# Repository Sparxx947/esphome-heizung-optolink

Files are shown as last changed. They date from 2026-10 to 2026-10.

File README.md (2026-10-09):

🇬🇧 [English version](README.en.md)

# Heizung · Optolink (Vitotronic 200 KW2 → ESPHome → Home Assistant)

Selbstbau-Lesekopf an der Optolink-Schnittstelle einer Viessmann-Ölheizung. Ein ESP32 mit ESPHome
liest Temperaturen, Brennerzustand, Brennerstunden und **Störmeldungen** aus der Regelung und gibt sie an
Home Assistant weiter. **Bewusst nur lesend** – die Firmware enthält nichts, was in die Regelung schreibt.

> Stand dieser Dokumentation: **08.10.2026**. Gerät geflasht und in HA, **Lesekopf noch nicht gelötet**
> (Fototransistor war für Fr 09.10. angekündigt, ist aber noch nicht da). Alle Optolink-Werte stehen deshalb in HA noch auf `unknown`.

> **Nachbauen:** Eigene Secrets nach der Vorlage [`firmware/secrets.example.yaml`](firmware/secrets.example.yaml)
> anlegen (WLAN, API-Schlüssel, Hotspot-Passwort) und die feste IP an das eigene Netz anpassen. Die Adressen in der
> Firmware gelten für die Vitotronic 200 KW2 – für andere Viessmann-Regelungen stehen sie im
> [openv-Wiki](https://github.com/openv/openv/wiki) (Seite „Adressen“).

---

## 1. Kurzbeschreibung

| | |
|---|---|
| **Anlage** | Ölkessel Viessmann **Vitola 111** (mit integriertem Speicher), Regelung **Vitotronic 200 Typ KW2** (witterungsgeführt, Gerätekennung `0x2098`), Brenner Viessmann VEA I-2 (Bj. 1999, max. 2,0 kg/h ≈ 2,4 l/h) |
| **Einbauort** | Heizungskeller, Lesekopf vorn links am „V“ der Regelung, ESP-Gehäuse magnetisch am Kesselblech |
| **Was gemessen wird** | Brennerstörung (Anzeige **D1**), Sammelstörung, Brenner an/aus, Pumpen, Außen-/Kessel-/Warmwasser-/Vorlauftemperaturen inkl. Sollwerte, Brennerstarts, **Brennerstunden** |
| **Was gesteuert wird** | nichts (absichtlich) |
| **Ziel** | Push bei Brennerstörung (Anlass: Störung D1 am 03./04.10.2026 bei leerem Tank, die niemand bemerkt hat); Ölverbrauch aus Brennerstunden × Düsendurchsatz als Grundlage für eine Tankprognose |

**Prinzip:** Die Vitotronic hat vorn hinter einem „V“-förmigen Ausschnitt zwei Lämpchen – eine IR-Empfangsdiode
(links, rot) und eine IR-Sendediode (rechts, grün). Darüber spricht sie seriell im **KW-Protokoll (VS1), 4800 Baud 8E2**.
Der Lesekopf setzt mit Magneten darauf: eine **IR-LED** (940 nm) sendet in die linke Lampe, ein **Fototransistor**
empfängt von der rechten. Der ESP32 bedient beide über einen UART (RX GPIO16 / TX GPIO17) mit der ESPHome-Komponente
`optolink` aus **ESPHome-PR #4453** (noch nicht in ESPHome gemergt). Schaltung nach VitoWiFi/openv-Wiki.

---

## 2. Status (Stand 08.10.2026)

| Bereich | Status | Datum / Bemerkung |
|---|---|---|
| Konzept, Adressen, Schaltung | ✅ fertig | 04.10. – Adressen aus openv-Tabelle V200KW2, **noch nicht am Display geprüft** |
| Firmware (YAML) | ✅ fertig, kompiliert | 04.10. (RAM 28 %, Flash 50 %), unverändert seither |
| ESP32 geflasht, WLAN, HA | ✅ fertig | 06.10. ~19:40 – `192.168.178.193`, HA-Integration „Heizung“, 24 Entitäten |
| Feste IP im Router | ✅ fertig | 06.10. (DHCP-Reservierung, immer gleiche IP) |
| Im ESPHome Builder | ✅ fertig, online | 06.10. ~20:00 – Builder-Fassung ist ab jetzt **führend** |
| Gehäuse (SCAD/STL) | ✅ fertig | 06.10. Maße eingetragen, 07.10. Boden + Stützen korrigiert („passt jetzt so“, Jens) |
| Gehäuse gedruckt | ✅ gedruckt | 08.10. laut Jens (ob es exakt die Fassung vom 07.10. ist, ist nicht ausdrücklich bestätigt) |
| Lesekopf löten | ⏳ offen | Fototransistor noch nicht geliefert (Stand 09.10. abends), Termin verschoben auf **Sa 10.10.** |
| Inbetriebnahme / Adressen prüfen | ⏳ offen | nach dem Löten, mit `optolink: logger: true` |
| HA-Automationen (Push, Ölverbrauch, Prognose) | ⏳ offen | erst nach erfolgreicher Inbetriebnahme |

---

## 3. Stückliste

Preise und ASINs zum Zeitpunkt der Bestellung (Amazon.de, Oktober 2026).

| Teil | Menge | Bezeichnung / Typ | Bezugsquelle, ASIN, Preis | Status |
|---|---|---|---|---|
| Mikrocontroller | 1 | **ESP32-WROOM-32U DevKitC V4**, USB-C, CP2102, IPEX-Antennenbuchse; Platine 48,24 × 28,15 mm | Amazon **B0F6567LB5**, 13,99 € (2 Stück bestellt, der zweite ist die Tankmessung) | ✅ geliefert 06.10., geflasht |
| Antenne | 1 | 2,4-GHz-Antenne mit IPEX→SMA-Pigtail (SMA-Buchse Ø ~6,4 mm, 1/4″) | im Antennen-Kit des ESP32 enthalten | ✅ vorhanden |
| IR-LED | 1 (+ Reserve) | **Chanzon** IR-LED 940 nm, 3 mm, 100 Stück (Ersatz für SFH487 / SIR 204 aus dem openv-Wiki) | Amazon **B01BVEKXNC**, 7,99 € | ✅ bestellt 04.10., Zustellung 06.10. angekündigt (Eingang nicht ausdrücklich notiert) |
| Fototransistor | 1 (+ Reserve) | **Kingbright L-93DP3C**, 3 mm, 940 nm, 5 Stück (Ersatz für SFH309FA) | Amazon **B01M3PGVRC**, 9,77 € (Marketplace) | ⏳ bestellt, Lieferung war für Fr 09.10. angekündigt – noch nicht da |
| Widerstand | 1 | 220 Ω (Vorwiderstand IR-LED) | AZ-Delivery-Widerstandssortiment | ✅ vorhanden |
| Widerstand | 1 | 10 kΩ (Pull-up Fototransistor) | AZ-Delivery-Widerstandssortiment | ✅ vorhanden |
| Magnete | 4 | Neodym-Scheibenmagnet **10 × 3 mm** (2 im Lesekopf, 2 im Boden des ESP-Gehäuses) | Amazon, Delaga, 50 Stück, 7,99 € | ✅ bestellt 04.10., Zustellung 06.10. angekündigt |
| Verbindungskabel | 4 | Dupont-Jumper **Buchse–Buchse** (F2F), Farbvorschlag rot/schwarz/gelb/grün | ELEGOO-Jumper-Set M2M/F2M/F2F (40 × 20 cm) | ✅ vorhanden |
| Stromversorgung | 1 | USB-C-Kabel + USB-Netzteil 5 V | – | ❓ **nicht in den Notizen** – vermutlich vorhanden, vor Einbau klären |
| Filament | ~20 g (geschätzt) | **PETG** (Wärme am Kessel) | vorhanden | ✅ vorhanden, Gehäuse gedruckt 08.10. |
| Kleber | wenig | Heißkleber (Platine auf Stützen fixieren, optional) bzw. Sekundenkleber für V-Schlüssel (optional) | vorhanden (angenommen) | ✅ |
| Schrauben | 0 | keine – Steckdeckel und Magnete | – | – |
| Werkzeug | – | Lötkolben, Multimeter (Diodentest), Messschieber, 3D-Drucker | vorhanden | ✅ |

Nicht verwendet, aber verwechslungsgefährdet: Das **AZ-Delivery-LED-Sortiment** ist sichtbares Licht und für Optolink
unbrauchbar. Das **ESP32-CAM-Set** (mit MB-Board) bleibt unangetastet – es war ursprünglich vorgesehen, wurde am
04.10. aber zugunsten eines neuen ESP32 verworfen.

Original-Bauteile laut openv/VitoWiFi: IR-LED **SFH487** (bzw. SIR 204 EVL), Fototransistor **SFH309FA** – bei Amazon
nicht erhältlich, bei Problemen als Tausch bei Reichelt möglich.

---

## 4. Pinbelegung und Verdrahtung

Schaltplan zum Ausdrucken: [`plaene/optolink-schaltplan.pdf`](plaene/optolink-schaltplan.pdf)
(SVG: [`plaene/optolink_plan.svg`](plaene/optolink_plan.svg), Erzeuger: [`plaene/optolink_plan.py`](plaene/optolink_plan.py)).

```
3,3 V ── 220 Ω ── IR-LED (Anode) │ Kathode ── GPIO17 (TX)
3,3 V ── 10 kΩ ──┬── GPIO16 (RX)
                 └── Kollektor Fototransistor │ Emitter ── GND
```

**Die Widerstände sitzen im Lesekopf**, zum ESP gehen nur vier Leitungen:

| Leitung | ESP32-Pin (Aufdruck) | Im Lesekopf an | Farbvorschlag |
|---|---|---|---|
| 1 | `3V3` | 220 Ω (zur LED-Anode) **und** 10 kΩ (zum FT-Kollektor) | rot |
| 2 | `GND` | Emitter Fototransistor | schwarz |
| 3 | `GPIO17` / „TX2“ / „17“ | Kathode IR-LED | gelb |
| 4 | `GPIO16` / „RX2“ / „16“ | Kollektor Fototransistor + 10 kΩ | grün |

**Beinchen:**

| Bauteil | Langes Bein | Kurzes Bein | Quelle |
|---|---|---|---|
| IR-LED (Chanzon) | Anode (+) → 220 Ω | Kathode (flache Seite) → GPIO17 | übliche LED-Konvention |
| Fototransistor L-93DP3C | Emitter → GND | **Kollektor** → GPIO16 + 10 kΩ | Kingbright-Datenblatt (DSAC1289), geprüft 06.10. |

Der Ausdruck nennt beim Fototransistor noch „meist kurzes Bein – prüfen!“; das ist inzwischen per Datenblatt bestätigt.
Trotzdem vor dem Löten mit dem Diodentest des Multimeters gegenprüfen. Falsch herum geht nichts kaputt, es kommen
nur keine Daten.

**Lage im Kopf** (Blick **auf** die Regelung = Blick auf die Rückseite des Kopfs beim Löten):

| Position | Lampe der Regelung | Funktion der Regelung | Unser Bauteil |
|---|---|---|---|
| links | rot („Störung“) | IR-Empfänger | **IR-LED** |
| rechts | grün („Betrieb“) | IR-Sender | **Fototransistor** |

Abstand der Lampen Mitte–Mitte: **14,4 mm** (Jens gemessen 06.10.; openv-Wiki nennt 14 mm).
Im Kopf ist innen „LED“, „FT“ und „OBEN“ eingeprägt.

---

## 5. Gehäuse

Quelle: [`gehaeuse/optolink-gehaeuse.scad`](gehaeuse/optolink-gehaeuse.scad) (OpenSCAD, parametrisch; Teil über
`TEIL = "…"` wählen). Geometrie des Kopfs angelehnt an `vito.scad` aus dem openv-Wiki.

| STL | Wofür | Maße (aus SCAD) | Druckausrichtung |
|---|---|---|---|
| [`kopf.stl`](gehaeuse/kopf.stl) | Lesekopf: Frontplatte 4 mm mit zwei Fenstern Ø 3,2 mm (14,4 mm Abstand), Kragenanschlag für die Bauteilfüße, 2 Magnettaschen 10,3 × 3,2 mm (0,6 mm Restwand zur Front), Hohlraum 12 mm für Widerstände, Kabelauslass 7 × 4 mm oben | Ø 34 mm, 16 mm tief | **Front aufs Bett** |
| [`kopf_deckel.stl`](gehaeuse/kopf_deckel.stl) | Rückdeckel mit Steckkragen und Kabelauslass für 4 Litzen | Ø 34 mm | flach |
| [`v_schluessel.stl`](gehaeuse/v_schluessel.stl) | Führungs-„V“, wird mit 2-mm-Zapfen in die Front gesteckt (ggf. geklebt) und greift ins „V“ der Regelung (ragt 6 mm vor, max. 8 zulässig) | Steg 1,6 mm | stehend |
| [`esp.stl`](gehaeuse/esp.stl) | Gehäuse für den ESP32: USB-C an der linken Stirnseite, SMA-Bohrung Ø 6,6 rechts **unter** der Platine, Dupont-Auslass 12 × 6 mm seitlich unten, Lüftungsschlitze, 2 Magnettaschen im Boden, Prägung „HEIZUNG“ | außen ca. 55,5 × 33,8 × 31 mm, innen 51,5 × 29,8 mm | Boden aufs Bett |
| [`esp_deckel.stl`](gehaeuse/esp_deckel.stl) | Steckdeckel | – | flach |

Vorschauen: [`vorschau_alle.png`](gehaeuse/vorschau_alle.png), [`vorschau_esp.png`](gehaeuse/vorschau_esp.png),
[`vorschau_kopf_vorn.png`](gehaeuse/vorschau_kopf_vorn.png), [`vorschau_kopf_hinten.png`](gehaeuse/vorschau_kopf_hinten.png).

**Druckeinstellungen:** PETG (Kesselnähe), 0,2 mm Schicht, 3 Wände, **ohne Stützmaterial**.

**Bestückung ESP-Gehäuse:** Die Platine liegt mit den beiden Stirnseiten auf **vier Stützen** (je Stirnseite zwei,
17 mm hoch, ca. 4,9 mm breit, 4,5 mm tief), die **zwischen den Stiftleisten** stehen: 3,2 mm Abstand zum Längsrand,
12 mm in der Mitte frei (dort sitzen die USB-Lötlaschen bzw. die SMA-Mutter). Bei Bedarf mit Heißkleber fixieren.
Unter der Platine ist Platz für die nach unten zeigenden Stifte und die Dupont-Buchsen. SMA-Buchse von innen durch
die Bohrung stecken, Mutter außen. Je ein Magnet in die beiden Bodentaschen (von unten), zwei in den Kopf (von hinten).

**Lehren aus den Fehldrucken** (Details in [`docs/verlauf.md`](docs/verlauf.md)):

| Fehler | Ursache | Korrektur |
|---|---|---|
| SMA-Bohrung wäre zugewachsen (06.10.) | lag hinter der rechten Platinenauflage | Bohrung unter die Platine (`sma_z = 8`), 12 mm Lücke für die Mutter |
| Magnettaschen gingen durch den Boden (07.10.) | Tasche 3,2 mm tief in 2,0-mm-Boden | `boden = 4.0` → 0,8 mm Restwand |
| Platine lag auf den Stiften (07.10.) | Stiftleisten laufen über die **ganze** Platinenlänge (19 × 2,54 = 48,3 mm); durchgehende Auflagen blockierten die Pins | 4 Einzelstützen zwischen den Pinreihen |

Regel daraus: Vor jedem STL-Export jede Tasche gegen die Wandstärke prüfen und die Platinen-Unterseite
(Stiftleisten, Buchsen, Lötlaschen) gegen jede Auflage; kritische Maße vorher messen lassen.

---

## 6. Firmware

Datei: [`firmware/heizung-optolink.yaml`](firmware/heizung-optolink.yaml) – entspricht dem Stand im ESPHome Builder.

| Einstellung | Wert |
|---|---|
| Gerätename / Hostname | `heizung-optolink` → `heizung-optolink.local` |
| Anzeigename (`friendly_name`) | `Heizung` |
| IP | **192.168.178.193** (feste DHCP-Reservierung in der FRITZ!Box) |
| Board / Framework | `esp32dev`, **Arduino** (Pflicht für die Optolink-Komponente) |
| Externe Komponente | `github://pr#4453`, Komponente `optolink` |
| Optolink | `protocol: KW`, `rx_pin: GPIO16`, `tx_pin: GPIO17`, `logger: false` (für Inbetriebnahme `true`) |
| Logger | `level: INFO`; UART0 bleibt für das USB-Log frei |
| API | verschlüsselt (`heizung_api_key`) |
| OTA | `platform: esphome`, ohne eigenes Passwort (abgesichert über den API-Schlüssel) |
| Fallback-Hotspot | SSID `Heizung-Fallback`, Passwort aus Secret, mit Captive Portal |

### Entitäten in Home Assistant (24)

Gerät „Heizung“ in der ESPHome-Integration. Die Entity-IDs ergeben sich nach ESPHome-Muster aus
`friendly_name` + Name (z. B. vermutlich `sensor.heizung_brennerstunden`) – **in HA nicht nachgesehen**.

| Name | Typ | Adresse | Format | Intervall |
|---|---|---|---|---|
| Brennerstörung (= Anzeige D1) | binär, problem | `0x0883` | 0/1 | 15 s |
| Sammelstörung | binär, problem | `0x0847` | 0/1 | 15 s |
| Brenner (1. Stufe) | binär, running | `0x0842` | 0/1 | 15 s |
| Speicherladepumpe | binär, running | `0x0845` | 0/1 | 60 s |
| Zirkulationspumpe | binär, running | `0x0846` | 0/1 | 60 s |
| Heizkreispumpe | binär, running | `0x2906` | 0/1 | 60 s |
| Außentemperatur | °C | `0x0800` | 2 B ÷ 10, vorzeichenbehaftet | 120 s |
| Außentemperatur gedämpft | °C | `0x5527` | 2 B ÷ 10, vorzeichenbehaftet | 600 s |
| Kesseltemperatur | °C | `0x0802` | 2 B ÷ 10 | 60 s |
| Kesselsolltemperatur | °C | `0x555A` | 2 B ÷ 10 | 120 s |
| Warmwassertemperatur (Speicher) | °C | `0x0804` | 2 B ÷ 10 | 120 s |
| Vorlauftemperatur (Sensor 17B) | °C | `0x080C` | 2 B ÷ 10 | 120 s |
| Vorlaufsolltemperatur (A1M1) | °C | `0x2544` | 2 B ÷ 10 | 300 s |
| Abgastemperatur (nur mit Abgasfühler sinnvoll) | °C, Diagnose | `0x0808` | 2 B ÷ 10 | 300 s |
| Brennerstarts | Zähler | `0x088A` | 4 B | 300 s |
| Brennerstunden (Stufe 1) | h, total_increasing | `0x08A7` | 4 B, Sekunden ÷ 3600 | 300 s |
| Ölverbrauch Regelung | Diagnose | `0x7574` | 4 B ÷ 1000 – **Bedeutung unklar**, erst beobachten | 1800 s |
| Betriebsart (Rohwert) | Diagnose | `0x2301` | 1 B | 600 s |
| Raumtemperatur Soll | °C, Diagnose | `0x2306` | 1 B | 600 s |
| Optolink-Warteschlange | Diagnose | – | `QUEUE_SIZE` | 60 s |
| Gerätekennung | Text, Diagnose | – | `DEVICE_INFO` | 1800 s |
| Optolink-Status | Text, Diagnose | – | `STATE_INFO` | 30 s |
| WLAN-Signal | dBm | – | – | 120 s |
| Laufzeit | s | – | – | 600 s |

Alle Adressen stammen aus der openv-Tabelle „Adressen“, Spalte V200KW2/KW1, und sind **noch nicht** gegen das
Display der Regelung geprüft.

### Secrets

[`firmware/secrets.example.yaml`](firmware/secrets.example.yaml) ist nur eine Vorlage mit den Schlüsselnamen
`wifi_ssid`, `wifi_password`, `heizung_api_key`, `heizung_ap_password`. **Echte Werte stehen nur im ESPHome Builder**
(dessen `secrets.yaml`), nie im Repo – `.gitignore` schließt `secrets.yaml` und `secrets.*.yaml` aus.
API-Schlüssel erzeugen: `openssl rand -base64 32`.

### Flashen

| Weg | Wann | Wie |
|---|---|---|
| **Builder, OTA** (Normalfall) | jede Änderung | YAML im ESPHome Builder bearbeiten → **INSTALL → Wirelessly** |
| **USB** (Erstflash / Notfall) | leeres Board, Gerät nicht mehr im WLAN | `esphome run heizung-optolink.yaml --no-logs --device /dev/ttyUSB0` mit **echten** Secrets (z. B. per podman-Image `ghcr.io/esphome/esphome`) |
| OTA vom PC (Notweg) | Builder nicht verfügbar | `esphome run … --no-logs --device 192.168.178.193` mit echten Secrets in einer temporären `secrets.yaml`, danach löschen |

> **Falle (06.10. passiert):** Nie einen Prüfbuild mit Dummy-Secrets flashen – das Gerät bekommt dann falsches
> Hotspot-Passwort und falschen API-Schlüssel. Und `esphome upload` **kompiliert nicht neu**, sondern spielt den
> letzten Build aus `.esphome/` auf. Für echte Firmware immer `esphome run`, auf „Successfully compiled“ achten und
> danach per API mit dem echten Schlüssel gegenprüfen.

Der Builder ist die führende Fassung. Wird dort etwas geändert, diese Datei hier nachziehen (und umgekehrt).

---

## 7. Anleitungen

Ausführlich in eigenen Dateien:

- [`docs/einbau.md`](docs/einbau.md) – Aufbau des Lesekopfs, Bestückung des Gehäuses, Montage am Kessel
- [`docs/einmessen.md`](docs/einmessen.md) – Inbetriebnahme, Adressen gegen das Display prüfen, Ölverbrauch aus Brennerstunden eichen
- [`docs/fehlersuche.md`](docs/fehlersuche.md) – bekannte Fehlerbilder mit Ursache und Lösung

### Kurzfassung

1. **Löten:** IR-LED links, Fototransistor rechts (Blick auf die Rückseite des Kopfs, „OBEN“ oben), Beinchen vorher
   per Diodentest prüfen, Widerstände im Kopf, 4 Dupont-Litzen durch den Kabelauslass.
2. **Gehäuse:** Magnete einsetzen, V-Schlüssel in die Front stecken, ESP auf die Stützen, Antenne an SMA.
3. **Firmware:** im Builder `optolink:` → `logger: true` setzen, **INSTALL → Wirelessly**.
4. **Aufsetzen:** Kopf mit dem V in den Ausschnitt der Regelung, ESP-Gehäuse magnetisch ans Kesselblech, USB-Strom.
5. **Prüfen:** Log zeigt Antworten, „Optolink-Status“ verlässt `unknown`, Gerätekennung `0x2098`(?);
   Kessel- und Außentemperatur mit dem Display vergleichen.
6. **Abschließen:** `logger: false`, erneut OTA; HA-Automationen anlegen (Abschnitt 8).

---

## 8. Home-Assistant-Anbindung

Im Repo liegen **keine HA-Pakete** (`ha/` gibt es hier nicht) – die Automationen sind noch nicht angelegt.
Geplant (Stand 04.–08.10.):

| Vorhaben | Grundlage | Status |
|---|---|---|
| Push bei **Brennerstörung** und **Sammelstörung** an die Hausbewohner | `binary_sensor` Brennerstörung / Sammelstörung → `on` | ⏳ geplant |
| Ölverbrauch | Brennerstunden × Düsendurchsatz (≤ 2,4 l/h), an Liefermengen eichen → [`docs/einmessen.md`](docs/einmessen.md) | ⏳ geplant |
| Tankprognose / Warnung | Vorwarnung bei **1.500 l**, dringend bei **800 l** | ⏳ geplant |

**Wichtig für die Automationen:** Ohne Kopf bzw. ohne Verbindung melden die Optolink-Binärsensoren `unknown`, nicht
`off`. Eine Automation „Brennerstörung = aus → alles gut“ würde sonst falsch beruhigen. Auch `unknown`/`unavailable`
über längere Zeit sollte gemeldet werden (Vorschlag, nicht umgesetzt).

Die parallele Füllstandsmessung am Erdtank (pneumatisch, ESP32 „Öltank“ `.194`) ist ein **eigenes Projekt** und
nicht Teil dieses Repos.

---

## 9. Offene Punkte, nächste Schritte, Termine

| Wann | Was | Wer |
|---|---|---|
| **Sa 10.10.2026** (verschoben vom 09.10.) | Sobald ein Fototransistor da ist → Lesekopf löten, aufsetzen, Inbetriebnahme mit `logger: true`. Kommen L-93DP3C und SFH 309 FA beide: **SFH 309 FA** nehmen (Tageslichtfilter); dessen Pinbelegung vor dem Löten im Datenblatt prüfen | Jens |
| beim Einbau | Klären, ob „Gehäuse passt“ (07.10.) nach Druck oder nach Vorschau galt – gedruckt wurde laut Jens am 08.10. | Jens |
| nach dem Löten | Adressen gegen das Display prüfen (v. a. Außen-, Kessel-, Warmwassertemperatur, Brennerzustand) | Jens + Claude |
| nach dem Löten | WLAN-Signal im Keller am Einbauort ablesen (am PC −47 dBm; Testling am Kessel 04.10. −41/−42 dBm) | – |
| danach | Bedeutung von „Ölverbrauch Regelung“ (`0x7574`) und „Betriebsart (Rohwert)“ beobachten | – |
| danach | HA: Push bei Störung, Ölverbrauch, Tankprognose | Claude |
| danach | Startwert für den Ölverbrauch erst nach der Peilung am Tank festlegen (Inhalt seit 05.10. vermutlich ~1.900 l, **unbestätigt**) | Jens |
| offen | Stromversorgung (USB-Netzteil, Kabelweg) am Kessel klären | Jens |
| bestellt 09.10. | **SFH 309 FA** (Reichelt) als Vorsorge, falls der L-93DP3C ausbleibt; SFH487 nur bei schlechtem Empfang | Jens |

---

## 10. Dateiübersicht

| Pfad | Inhalt |
|---|---|
| `README.md` | diese Übersicht |
| `docs/einbau.md` | Aufbau und Montage Schritt für Schritt |
| `docs/einmessen.md` | Inbetriebnahme, Adressprüfung, Ölverbrauchs-Abgleich |
| `docs/fehlersuche.md` | Fehlerbilder, Ursachen, Lösungen |
| `docs/verlauf.md` | Projektverlauf mit Datum |
| `firmware/heizung-optolink.yaml` | ESPHome-Konfiguration (Stand Builder) |
| `firmware/secrets.example.yaml` | Vorlage für die Secrets (ohne echte Werte) |
| `gehaeuse/optolink-gehaeuse.scad` | OpenSCAD-Quelltext aller Gehäuseteile |
| `gehaeuse/kopf.stl`, `kopf_deckel.stl`, `v_schluessel.stl` | Lesekopf mit Deckel und Führungs-V |
| `gehaeuse/esp.stl`, `esp_deckel.stl` | ESP32-Gehäuse mit Deckel |
| `gehaeuse/vorschau_*.png` | Renderbilder |
| `plaene/optolink-schaltplan.pdf` | Schaltplan + Anschlusstabelle + Lage im Kopf (A4) |
| `plaene/optolink_plan.svg` | dasselbe als SVG |
| `plaene/optolink_plan.py` | matplotlib-Skript, das den Plan erzeugt (Ausgabepfade darin sind lokal) |
| `.gitignore` | schließt Secrets, Build-Ordner und Sicherungskopien aus |

**Quellen:** openv-Wiki („Die Optolink-Schnittstelle“, „ESPHome-Optolink“, „Adressen“, `vito.scad`), VitoWiFi,
ESPHome-PR #4453.

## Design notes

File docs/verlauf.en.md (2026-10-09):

🇩🇪 [Deutsche Version](verlauf.md)

# Project history

| Date | What |
|---|---|
| 03./04.10.2026 | Fault **D1** (burner fault) on the Vitotronic – tank empty, nobody noticed. Idea: read out the Optolink and report to HA. |
| 04.10. | Type plate: Vitotronic 200 **KW2**. Approach decided: ESPHome PR #4453 (`protocol: KW`), circuit according to openv/VitoWiFi, addresses from the openv table V200KW2. |
| 04.10. | Wi-Fi test at the boiler with a D1 mini: −41/−42 dBm (AP directly in front of the boiler room). |
| 04.10. | Decision: the ESP32-CAM set remains untouched, instead a new **ESP32-WROOM-32U DevKitC** with external antenna. |
| 04.10. | Ordered: 2× ESP32 + IR LEDs (delivery 06.10.), phototransistor L-93DP3C (delivery 09.10.), magnets 10 × 3 mm (06.10.). |
| 04.10. | `heizung-optolink.yaml` written, validated and compiled (RAM 28 %, flash 50 %); enclosure SCAD + STL first version. |
| 05.10. | Oil delivered (1,500 l), burner runs again after bleeding. |
| 06.10. | Dimensions measured (Jens): board 48.24 × 28.15 mm, USB-C protrudes 1.6 mm, lamp distance **14.4 mm** → SCAD adapted. SMA hole moved below the board. |
| 06.10. ~19:40 | ESP32 flashed, `192.168.178.193`, HA integration "Heizung" (heating) with 24 entities. **Trap:** first flashed the test build with dummy secrets, `upload` did not recompile → corrected with `esphome run` and real secrets. |
| 06.10. ~20:00 | Added to the ESPHome Builder, online; Builder version authoritative from now on. Fixed IP in the FRITZ!Box. |
| 06.10. evening | Datasheet L-93DP3C checked: **collector = short leg**. Circuit diagram printed. |
| 07.10. | First print of the ESP enclosure (Jens) shows two faults: magnet pockets through the floor, supports under the pin headers → floor 4 mm, 4 supports between the pin rows. Jens: "fits like this now". |
| 07.10. | USB access on the PC permanently solved via a udev rule. |
| 08.10. | Optolink enclosure printed (according to Jens). |
| 08.10. | Documentation repo created. |
| 09.10. | Phototransistor (L-93DP3C) not delivered; SFH 309 FA ordered from Reichelt as a fallback. Read-head appointment moved to Sat 10.10. |
| **10.10.** | planned: solder the read head, attach, commissioning with `logger: true`, check addresses (as soon as a phototransistor is available). |

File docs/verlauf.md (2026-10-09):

🇬🇧 [English version](verlauf.en.md)

# Projektverlauf

| Datum | Was |
|---|---|
| 03./04.10.2026 | Störung **D1** (Brennerstörung) an der Vitotronic – Tank leer, niemand hat es bemerkt. Idee: Optolink auslesen und in HA melden. |
| 04.10. | Typschild: Vitotronic 200 **KW2**. Weg festgelegt: ESPHome-PR #4453 (`protocol: KW`), Schaltung nach openv/VitoWiFi, Adressen aus der openv-Tabelle V200KW2. |
| 04.10. | WLAN-Test am Kessel mit einem D1 mini: −41/−42 dBm (AP direkt vor dem Heizungskeller). |
| 04.10. | Entscheidung: ESP32-CAM-Set bleibt unangetastet, stattdessen neuer **ESP32-WROOM-32U DevKitC** mit externer Antenne. |
| 04.10. | Bestellt: 2× ESP32 + IR-LEDs (Zustellung 06.10.), Fototransistor L-93DP3C (Zustellung 09.10.), Magnete 10 × 3 mm (06.10.). |
| 04.10. | `heizung-optolink.yaml` geschrieben, validiert und kompiliert (RAM 28 %, Flash 50 %); Gehäuse-SCAD + STL erster Stand. |
| 05.10. | Öl geliefert (1.500 l), Brenner läuft nach Entlüften wieder. |
| 06.10. | Maße gemessen (Jens): Platine 48,24 × 28,15 mm, USB-C ragt 1,6 mm über, Lampenabstand **14,4 mm** → SCAD angepasst. SMA-Bohrung unter die Platine verlegt. |
| 06.10. ~19:40 | ESP32 geflasht, `192.168.178.193`, HA-Integration „Heizung“ mit 24 Entitäten. **Falle:** zuerst Prüfbuild mit Dummy-Secrets geflasht, `upload` kompilierte nicht neu → mit `esphome run` und echten Secrets korrigiert. |
| 06.10. ~20:00 | Im ESPHome Builder eingetragen, online; Builder-Fassung ab jetzt führend. Feste IP in der FRITZ!Box. |
| 06.10. abends | Datenblatt L-93DP3C geprüft: **Kollektor = kurzes Bein**. Schaltplan gedruckt. |
| 07.10. | Erster Druck des ESP-Gehäuses (Jens) zeigt zwei Fehler: Magnettaschen durch den Boden, Auflagen unter den Stiftleisten → Boden 4 mm, 4 Stützen zwischen den Pinreihen. Jens: „passt jetzt so“. |
| 07.10. | USB-Zugriff am PC per udev-Regel dauerhaft gelöst. |
| 08.10. | Optolink-Gehäuse gedruckt (laut Jens). |
| 08.10. | Doku-Repo angelegt. |
| 09.10. | Fototransistor (L-93DP3C) nicht geliefert; als Vorsorge SFH 309 FA bei Reichelt bestellt. Lesekopf-Termin auf Sa 10.10. verschoben. |
| **10.10.** | geplant: Lesekopf löten, aufsetzen, Inbetriebnahme mit `logger: true`, Adressen prüfen (sobald ein Fototransistor da ist). |

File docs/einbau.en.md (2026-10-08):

🇩🇪 [Deutsche Version](einbau.md)

# Assembly and installation

Step by step from the components to the attached read head. Circuit diagram to keep at hand:
[`../plaene/optolink-schaltplan.pdf`](../plaene/optolink-schaltplan.pdf).

## Prepare beforehand

- printed parts: `kopf` (head), `kopf_deckel` (head lid), `v_schluessel` (V key), `esp`, `esp_deckel` (ESP lid) (PETG)
- IR LED Chanzon 940 nm, phototransistor Kingbright L-93DP3C, 220 Ω, 10 kΩ
- 4 neodymium magnets 10 × 3 mm
- 4 Dupont wires female–female (red, black, yellow, green)
- ESP32-WROOM-32U DevKitC (already flashed) with antenna + IPEX→SMA pigtail
- Soldering iron, multimeter, heat-shrink tubing/insulating tape, hot glue if needed

## 1. Check the components

1. **IR LED:** long leg = anode (+), short leg/flat side = cathode.
   Diode test: red on the anode, black on the cathode → the forward voltage is displayed.
2. **Phototransistor L-93DP3C:** according to the datasheet **collector = short leg**, emitter = long leg.
   Double-check with the multimeter (resistance collector→emitter drops significantly with light or remote-control IR).
3. Installing it the wrong way round destroys nothing – you just get no data.

## 2. Solder the read head

1. Hold the head with its back towards you, embossing **"OBEN" (top) facing up**.
   Then the same side applies as when looking at the controller:
   - **left ("LED")** → IR LED (transmits into the controller's red receiving lamp)
   - **right ("FT", phototransistor)** → phototransistor (receives from the green transmitting lamp)
2. Insert both components from behind into the windows until the component base rests against the collar; the lens is
   flush with the front (4 mm). Secure with a drop of glue if needed.
3. Wire up in the cavity (12 mm deep):

   | From | To |
   |---|---|
   | red (3V3) | 220 Ω → LED anode **and** 10 kΩ → PT collector |
   | yellow (GPIO17) | LED cathode |
   | green (GPIO16) | PT collector (together with the 10 kΩ) |
   | black (GND) | PT emitter |

4. Insulate the solder joints, route the four strands out through the cable outlet at the top (7 × 4 mm).
5. **Two magnets** from behind into the pockets above and below the windows (0.6 mm remaining wall to the front – they hold
   through it). Polarity such that the head sticks to the controller.
6. Plug the **V key** with its 2 mm peg into the pocket in the front (tip pointing down), glue if needed.
7. Push on `kopf_deckel` (head lid); the cable outlet in the push-fit collar must be above the one in the head.

## 3. Fit out the ESP enclosure

1. One magnet each from below into the two floor pockets (0.8 mm remaining wall).
2. SMA socket of the pigtail from the inside through the hole at the bottom right (Ø 6.6 mm), tighten the nut on the outside.
   The hole is deliberately **below** the board.
3. Press the pigtail onto the ESP32's IPEX connector.
4. Plug the Dupont wires onto the pins `3V3`, `GND`, `GPIO17`, `GPIO16` (see the table in the README).
5. Place the board with **USB-C towards the left end face** on the four supports. The supports stand between the
   pin rows; below them there is room for pins and Dupont sockets. Fix with hot glue if needed.
6. Route the Dupont wires through the side outlet (12 × 6 mm, near the USB side).
7. Push on the lid.

## 4. Mounting on the boiler

1. Place the read head with the V key into the "V" cut-out of the Vitotronic (front left); the magnets hold it.
   The V web protrudes 6 mm, the controller allows at most 8 mm.
2. Attach the ESP enclosure magnetically to the boiler sheet metal within reach of the strands.
3. Screw the antenna onto the SMA socket.
4. Connect USB-C power (power supply/cable route not yet defined in the notes).
5. Continue with [`einmessen.en.md`](einmessen.en.md).

## Notes

- The "Entsperrung" (unlock) button on the controller is the **STB** (safety temperature limiter), not the burner reset. The burner reset is the red
  reset button on the burner control unit (Landis & Gyr LOA24). For this project neither needs to be pressed.
- Do not touch the AFRISO leak detector on the tank gauge (belongs to the tank, not to this project).

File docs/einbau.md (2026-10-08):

🇬🇧 [English version](einbau.en.md)

# Aufbau und Einbau

Schritt für Schritt vom Bauteil zum aufgesetzten Lesekopf. Schaltplan zum Danebenlegen:
[`../plaene/optolink-schaltplan.pdf`](../plaene/optolink-schaltplan.pdf).

## Vorher bereitlegen

- gedruckte Teile: `kopf`, `kopf_deckel`, `v_schluessel`, `esp`, `esp_deckel` (PETG)
- IR-LED Chanzon 940 nm, Fototransistor Kingbright L-93DP3C, 220 Ω, 10 kΩ
- 4 Neodym-Magnete 10 × 3 mm
- 4 Dupont-Leitungen Buchse–Buchse (rot, schwarz, gelb, grün)
- ESP32-WROOM-32U DevKitC (schon geflasht) mit Antenne + IPEX→SMA-Pigtail
- Lötkolben, Multimeter, Schrumpfschlauch/Isolierband, ggf. Heißkleber

## 1. Bauteile prüfen

1. **IR-LED:** langes Bein = Anode (+), kurzes Bein/flache Seite = Kathode.
   Diodentest: rot an Anode, schwarz an Kathode → Durchlassspannung wird angezeigt.
2. **Fototransistor L-93DP3C:** laut Datenblatt **Kollektor = kurzes Bein**, Emitter = langes Bein.
   Mit dem Multimeter gegenprüfen (Widerstand Kollektor→Emitter fällt bei Licht bzw. Fernbedienungs-IR deutlich).
3. Falsch eingebaut zerstört nichts – es kommen dann nur keine Daten.

## 2. Lesekopf löten

1. Kopf mit der Rückseite zu dir halten, Prägung **„OBEN“ nach oben**.
   Dann gilt dieselbe Seite wie beim Blick auf die Regelung:
   - **links („LED“)** → IR-LED (sendet in die rote Empfangslampe der Regelung)
   - **rechts („FT“)** → Fototransistor (empfängt von der grünen Sendelampe)
2. Beide Bauteile von hinten in die Fenster stecken, bis der Bauteilfuß am Kragen anliegt; die Linse schließt mit der
   Front (4 mm) bündig ab. Ggf. mit einem Tropfen Kleber sichern.
3. Im Hohlraum (12 mm tief) verdrahten:

   | Von | Nach |
   |---|---|
   | rot (3V3) | 220 Ω → LED-Anode **und** 10 kΩ → FT-Kollektor |
   | gelb (GPIO17) | LED-Kathode |
   | grün (GPIO16) | FT-Kollektor (gemeinsam mit dem 10 kΩ) |
   | schwarz (GND) | FT-Emitter |

4. Lötstellen isolieren, die vier Litzen oben durch den Kabelauslass (7 × 4 mm) führen.
5. **Zwei Magnete** von hinten in die Taschen ober- und unterhalb der Fenster (0,6 mm Restwand zur Front – sie halten
   durch). Polung so, dass der Kopf an der Regelung hält.
6. **V-Schlüssel** mit dem 2-mm-Zapfen in die Tasche in der Front stecken (Spitze nach unten), bei Bedarf kleben.
7. `kopf_deckel` aufstecken; der Kabelauslass im Steckkragen muss über dem im Kopf liegen.

## 3. ESP-Gehäuse bestücken

1. Je einen Magneten von unten in die beiden Bodentaschen (0,8 mm Restwand).
2. SMA-Buchse des Pigtails von innen durch die Bohrung rechts unten (Ø 6,6 mm), Mutter außen festziehen.
   Die Bohrung liegt bewusst **unter** der Platine.
3. Pigtail auf die IPEX-Buchse des ESP32 drücken.
4. Dupont-Leitungen auf die Stifte `3V3`, `GND`, `GPIO17`, `GPIO16` stecken (siehe Tabelle im README).
5. Platine mit **USB-C zur linken Stirnseite** auf die vier Stützen legen. Die Stützen stehen zwischen den
   Stiftreihen; darunter haben Stifte und Dupont-Buchsen Platz. Bei Bedarf mit Heißkleber fixieren.
6. Dupont-Leitungen durch den seitlichen Auslass (12 × 6 mm, nahe der USB-Seite) führen.
7. Deckel aufstecken.

## 4. Montage am Kessel

1. Lesekopf mit dem V-Schlüssel in den „V“-Ausschnitt der Vitotronic setzen (vorn links); die Magnete halten ihn.
   Der V-Steg ragt 6 mm vor, die Regelung erlaubt höchstens 8 mm.
2. ESP-Gehäuse in Reichweite der Litzen magnetisch an das Kesselblech setzen.
3. Antenne an die SMA-Buchse schrauben.
4. USB-C-Strom anschließen (Netzteil/Kabelweg ist in den Notizen noch nicht festgelegt).
5. Weiter mit [`einmessen.md`](einmessen.md).

## Hinweise

- Der „Entsperrung“-Knopf an der Regelung ist der **STB**, nicht der Brenner-Reset. Der Brenner-Reset ist der rote
  Entstörknopf am Feuerungsautomaten (Landis & Gyr LOA24). Für dieses Projekt muss keins von beiden betätigt werden.
- Den AFRISO-Leckanzeiger an der Tankanzeige nicht anfassen (gehört zum Tank, nicht hierher).

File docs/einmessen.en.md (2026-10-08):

🇩🇪 [Deutsche Version](einmessen.md)

# Commissioning and calibration

With Optolink there is nothing analogue to calibrate – the controller delivers finished values. "Calibration" here means:

1. proving **communication**,
2. checking the **addresses** against the controller's display (they come unverified from the openv table),
3. calibrating the **oil consumption** from the burner hours against real delivered or dipped quantities.

## 1. Prove communication

1. In the ESPHome Builder in `heizung-optolink.yaml`:
   ```yaml
   optolink:
     logger: true      # war false
   ```
   (`# war false` = "was false".) If necessary, additionally set `logger: level: DEBUG` in case no Optolink lines appear at `INFO`
   (whether this is needed has **not been checked**).
2. **INSTALL → Wirelessly**, then open **LOGS** in the Builder.
3. Expected:
   - Responses to the requests appear in the log.
   - Text sensor **"Optolink-Status"** changes away from `communication state unknown`.
   - **"Gerätekennung"** (device ID) should identify the V200KW2 (device ID according to openv `0x2098` or identifier `0x00F8`
     in the address table; which format exactly the sensor outputs is open).
   - **"Optolink-Warteschlange"** (Optolink queue) stays small and does not grow steadily.
4. If nothing comes: [`fehlersuche.en.md`](fehlersuche.en.md).

## 2. Check addresses against the display

Compare the values in HA (or in the log) with the Vitotronic's display. Deviations ≤ 0.5 K are rounding.

| Check | HA entity | Address | Comparison on the display | Expectation |
|---|---|---|---|---|
| Outdoor temperature | Außentemperatur | `0x0800` | query outdoor temperature | equal; **negative** in frost (min_value −60 forces signed reading) |
| Boiler | Kesseltemperatur | `0x0802` | boiler temperature | equal |
| Hot water | Warmwassertemperatur | `0x0804` | tank temperature | equal |
| Flow | Vorlauftemperatur | `0x080C` | only if sensor 17B is present | otherwise implausible/constant |
| Flue gas | Abgastemperatur | `0x0808` | only if a flue gas sensor is installed | otherwise implausible → disable entity |
| Burner | Brenner | `0x0842` | flame / burner running | `on` while the burner is running |
| Pumps | Speicherlade-, Zirkulations-, Heizkreispumpe (tank charging, circulation, heating circuit pump) | `0x0845`, `0x0846`, `0x2906` | pump audible/palpable | matches operation |
| Burner hours | Brennerstunden | `0x08A7` | operating hours in the controller | equal (seconds ÷ 3600) |
| Burner starts | Brennerstarts | `0x088A` | burner starts | equal |
| Fault | Brennerstörung / Sammelstörung (burner fault / general fault) | `0x0883` / `0x0847` | fault display | `off` in normal operation |
| Operating mode | Betriebsart (Rohwert) | `0x2301` | set operating mode | note the raw value, observe the mapping |
| Oil consumption controller | Ölverbrauch Regelung | `0x7574` | – | **function unclear** – observe only |

Correct addresses that do not match in the YAML or disable the entity; record the result in [`verlauf.en.md`](verlauf.en.md).
Then `optolink: logger: false` and OTA again.

## 3. Calibrate oil consumption from burner hours

### Basic formula

```
Verbrauch [l] = (Brennerstunden_Ende − Brennerstunden_Anfang) [h] × q [l/h]
```

(Consumption [l] = (burner hours at end − burner hours at start) [h] × q [l/h].)

**Starting value for q:** The burner (VEA I-2) is rated at max. **2.0 kg/h**. With heating oil EL ρ ≈ 0.84 kg/l:

```
q_max = 2,0 kg/h ÷ 0,84 kg/l ≈ 2,38 l/h   (≈ 2,4 l/h)
```

That is the **maximum value**; the actual nozzle is not documented, so q is more likely lower.

### Calibrating against delivered and dipped quantities

Between two points in time with known tank content (dipping or full delivery):

```
q = (Inhalt_Anfang + Lieferungen_dazwischen − Inhalt_Ende) [l]
    ÷ (Brennerstunden_Ende − Brennerstunden_Anfang) [h]
```

(q = (content at start + deliveries in between − content at end) [l] ÷ (burner hours at end − burner hours at start) [h].)

Procedure:

1. **Set the starting point:** dip the tank (dipstick in the manhole) and at the same time note the "Brennerstunden" (burner hours) reading.
   Since the delivery on 05.10. (1,500 l) the content according to the gauge is ~1,900 l – this is **not confirmed**
   (the old pneumatic gauge was silted up). Dipping reference values (horizontal cylinder Ø 1.6 m, ends neglected):
   1,500 l ≈ 42.7 cm, 1,700 l ≈ 46.7 cm, 1,900 l ≈ 50.6 cm.
2. **End point:** at the next delivery or after a few weeks, dip again + note the burner hours.
3. Calculate q using the formula and store it in HA as a factor.
4. Plausibility: previous deliveries (3,000 l on 20.09.2024, 3,000 l on 04.08.2025) lasted ~14 months;
   annual consumption ~2,800 l. With q = 2.38 l/h this would be ~1,180 burner hours/year (**derived**, not measured) –
   an annual value of burner hours from the controller immediately shows whether q is in the right order of magnitude.

### Tank forecast (planned)

```
Restinhalt = Inhalt_Anfang + Lieferungen − q × (Brennerstunden_jetzt − Brennerstunden_Anfang)
```

(Remaining content = content at start + deliveries − q × (burner hours now − burner hours at start).)

Warning thresholds according to the plan: **early warning 1,500 l**, **urgent 800 l**. A suggestion for an HA template sensor,
**not yet set up** and with an **unverified** entity ID:

```yaml
template:
  - sensor:
      - name: Heizöl Restinhalt (Brennerstunden)
        unit_of_measurement: l
        state: >
          {% set h = states('sensor.heizung_brennerstunden') | float(none) %}
          {% if h is none %}{{ none }}{% else %}
          {{ (1900 - 2.38 * (h - BRENNERSTUNDEN_BEI_PEILUNG)) | round(0) }}
          {% endif %}
```

(`Heizöl Restinhalt (Brennerstunden)` = heating oil remaining content (burner hours); `BRENNERSTUNDEN_BEI_PEILUNG` = burner hours at the time of dipping.)

`1900`, `2.38` and `BRENNERSTUNDEN_BEI_PEILUNG` are placeholders – better create them as `input_number` helpers so that
dipping and deliveries can be entered without changing the YAML.

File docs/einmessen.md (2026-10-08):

🇬🇧 [English version](einmessen.en.md)

# Inbetriebnahme und Einmessen

Beim Optolink gibt es nichts analog zu kalibrieren – die Regelung liefert fertige Werte. „Einmessen“ heißt hier:

1. **Kommunikation** nachweisen,
2. **Adressen** gegen das Display der Regelung prüfen (sie stammen ungeprüft aus der openv-Tabelle),
3. den **Ölverbrauch** aus den Brennerstunden an echten Liefer- bzw. Peilmengen eichen.

## 1. Kommunikation nachweisen

1. Im ESPHome Builder in `heizung-optolink.yaml`:
   ```yaml
   optolink:
     logger: true      # war false
   ```
   Ggf. zusätzlich `logger: level: DEBUG` setzen, falls bei `INFO` keine Optolink-Zeilen erscheinen
   (ob nötig, ist **nicht geprüft**).
2. **INSTALL → Wirelessly**, danach im Builder **LOGS** öffnen.
3. Erwartung:
   - Im Log erscheinen Antworten auf die Anfragen.
   - Text-Sensor **„Optolink-Status“** wechselt weg von `communication state unknown`.
   - **„Gerätekennung“** sollte die V200KW2 ausweisen (Geräte-ID laut openv `0x2098` bzw. Kennung `0x00F8`
     in der Adressen-Tabelle; welches Format der Sensor genau ausgibt, ist offen).
   - **„Optolink-Warteschlange“** bleibt klein und läuft nicht stetig hoch.
4. Kommt nichts: [`fehlersuche.md`](fehlersuche.md).

## 2. Adressen gegen das Display prüfen

Werte in HA (oder im Log) mit der Anzeige der Vitotronic vergleichen. Abweichungen ≤ 0,5 K sind Rundung.

| Prüfen | HA-Entität | Adresse | Vergleich am Display | Erwartung |
|---|---|---|---|---|
| Außentemperatur | Außentemperatur | `0x0800` | Abfrage Außentemperatur | gleich; bei Frost **negativ** (min_value −60 erzwingt vorzeichenbehaftetes Lesen) |
| Kessel | Kesseltemperatur | `0x0802` | Kesseltemperatur | gleich |
| Warmwasser | Warmwassertemperatur | `0x0804` | Speichertemperatur | gleich |
| Vorlauf | Vorlauftemperatur | `0x080C` | nur falls Fühler 17B vorhanden | sonst unplausibel/konstant |
| Abgas | Abgastemperatur | `0x0808` | nur falls Abgasfühler verbaut | sonst unplausibel → Entität deaktivieren |
| Brenner | Brenner | `0x0842` | Flamme / Brenner läuft | `on` während der Brenner läuft |
| Pumpen | Speicherlade-, Zirkulations-, Heizkreispumpe | `0x0845`, `0x0846`, `0x2906` | Pumpe hörbar/fühlbar | passt zum Betrieb |
| Brennerstunden | Brennerstunden | `0x08A7` | Betriebsstunden in der Regelung | gleich (Sekunden ÷ 3600) |
| Brennerstarts | Brennerstarts | `0x088A` | Brennerstarts | gleich |
| Störung | Brennerstörung / Sammelstörung | `0x0883` / `0x0847` | Störungsanzeige | im Normalbetrieb `off` |
| Betriebsart | Betriebsart (Rohwert) | `0x2301` | eingestellte Betriebsart | Rohwert notieren, Zuordnung beobachten |
| Ölverbrauch Regelung | Ölverbrauch Regelung | `0x7574` | – | **Funktion unklar** – nur beobachten |

Nicht passende Adressen in der YAML korrigieren oder die Entität deaktivieren; das Ergebnis in [`verlauf.md`](verlauf.md)
nachtragen. Danach `optolink: logger: false` und erneut OTA.

## 3. Ölverbrauch aus Brennerstunden eichen

### Grundformel

```
Verbrauch [l] = (Brennerstunden_Ende − Brennerstunden_Anfang) [h] × q [l/h]
```

**Startwert für q:** Der Brenner (VEA I-2) ist mit max. **2,0 kg/h** angegeben. Mit Heizöl EL ρ ≈ 0,84 kg/l:

```
q_max = 2,0 kg/h ÷ 0,84 kg/l ≈ 2,38 l/h   (≈ 2,4 l/h)
```

Das ist der **Höchstwert**; die tatsächliche Düse ist nicht dokumentiert, q liegt also eher darunter.

### Eichen an Liefer- und Peilmengen

Zwischen zwei Zeitpunkten mit bekanntem Tankinhalt (Peilung oder volle Lieferung):

```
q = (Inhalt_Anfang + Lieferungen_dazwischen − Inhalt_Ende) [l]
    ÷ (Brennerstunden_Ende − Brennerstunden_Anfang) [h]
```

Ablauf:

1. **Anfangspunkt setzen:** Tank peilen (Peilstab im Domschacht) und gleichzeitig den Stand „Brennerstunden“ notieren.
   Seit der Lieferung am 05.10. (1.500 l) liegt der Inhalt laut Anzeige bei ~1.900 l – das ist **nicht bestätigt**
   (die alte pneumatische Anzeige war verschlammt). Peil-Richtwerte (liegender Zylinder Ø 1,6 m, Böden vernachlässigt):
   1.500 l ≈ 42,7 cm, 1.700 l ≈ 46,7 cm, 1.900 l ≈ 50,6 cm.
2. **Endpunkt:** bei der nächsten Lieferung bzw. nach einigen Wochen erneut peilen + Brennerstunden notieren.
3. q nach der Formel rechnen und in HA als Faktor hinterlegen.
4. Plausibilität: Bisherige Lieferungen (3.000 l am 20.09.2024, 3.000 l am 04.08.2025) reichten ~14 Monate;
   Jahresverbrauch ~2.800 l. Bei q = 2,38 l/h wären das ~1.180 Brennerstunden/Jahr (**abgeleitet**, nicht gemessen) –
   ein Jahreswert der Brennerstunden aus der Regelung zeigt sofort, ob q in der richtigen Größenordnung liegt.

### Tankprognose (geplant)

```
Restinhalt = Inhalt_Anfang + Lieferungen − q × (Brennerstunden_jetzt − Brennerstunden_Anfang)
```

Warnschwellen laut Plan: **Vorwarnung 1.500 l**, **dringend 800 l**. Ein Vorschlag für einen HA-Template-Sensor,
noch **nicht eingerichtet** und mit **ungeprüfter** Entity-ID:

```yaml
template:
  - sensor:
      - name: Heizöl Restinhalt (Brennerstunden)
        unit_of_measurement: l
        state: >
          {% set h = states('sensor.heizung_brennerstunden') | float(none) %}
          {% if h is none %}{{ none }}{% else %}
          {{ (1900 - 2.38 * (h - BRENNERSTUNDEN_BEI_PEILUNG)) | round(0) }}
          {% endif %}
```

`1900`, `2.38` und `BRENNERSTUNDEN_BEI_PEILUNG` sind Platzhalter – besser als `input_number`-Helfer anlegen, damit
Peilung und Lieferungen ohne YAML-Änderung nachgetragen werden können.

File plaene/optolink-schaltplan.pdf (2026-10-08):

# Optolink-Lesekopf Schaltplan

Vitotronic 200 KW2 · ESP32-WROOM-32U DevKitC · ESPHome heizung-optolink (192.168.178.193) · Stand 06.10.2026

3V3

## GND

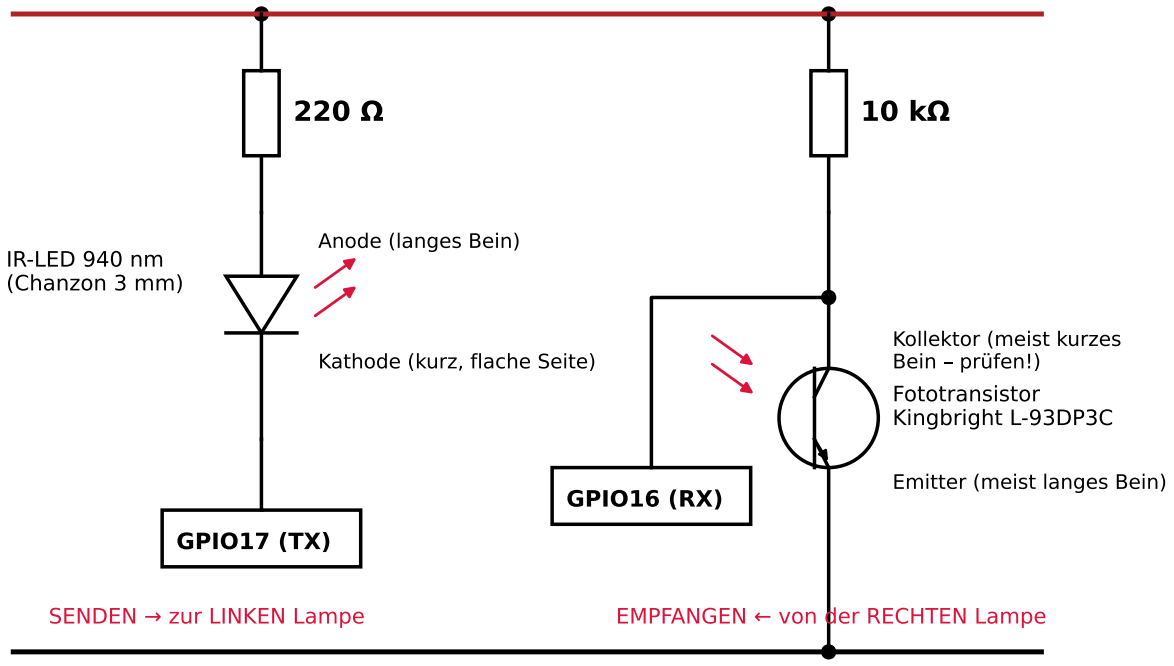
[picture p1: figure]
IR-LED 940 nm (Chanzon 3 mm); Anode (langes Bein); Kathode (kurz, flache Seite); GPIO17 (TX); SENDEN; zur LINKEN Lampe; GPIO16 (RX); Kollektor (meist kurzes; Bein; prüfen!); Emitter (meist langes Bein); Fototransistor Kingbright L-93DP3C; EMPFANGEN; von der RECHTEN Lampe

Achtung Beinchen: Bei der LED ist das LANGE Bein die Anode (+). Beim Fototransistor ist meist das LANGE Bein der Emitter ( ) vor dem Löten am Datenblatt bzw. mit dem Multimeter (Diodentest) prüfen. Falsch herum: nichts kaputt, aber keine Daten.

Verbindung Lesekopf | ESP32 (4 Dupont-Leitungen, Buchse Buchse)
Leitung | ESP32-Pin | Im Lesekopf an | Farbvorschlag
1 | 3V3 | 220 | (LED) + 10 k (FT) | rot
2 | GND | Emitter Fototransistor | schwarz
3 | GPIO17 / TX2 / 17 | Kathode IR-LED | gelb
4 | GPIO16 / RX2 / 16 | Kollektor FT + 10 k | grün

## Lage im Lesekopf (Blick AUF die Regelung = Blick auf die Rückseite des Kopfs)

LED | FT

OBEN

14,4 mm

LINKE Lampe (rot, Störung) = Empfänger der Regelung dort unsere IR-LED

RECHTE Lampe (grün, Betrieb) = Sender der Regelung
dort unser Fototransistor

Abstand Mitte Mitte 14,4 mm (gemessen 06.10.), Kopf-STL ist angepasst

Widerstände sitzen im Kopf, nur 4 Leitungen zum ESP-Gehäuse

Quelle: Schaltung nach VitoWiFi/openv-Wiki ( Die Optolink-Schnittstelle , ESPHome-Optolink ), festgelegt 04.10. in ~/esphome/heizung-optolink.yaml. UART 4800 8E2, Protokoll KW. Inbetriebnahme: optolink logger: true, Werte mit der Anzeige der Regelung vergleichen.

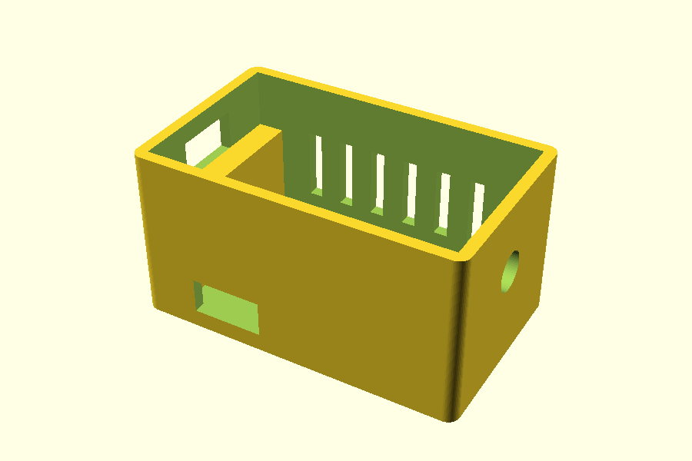
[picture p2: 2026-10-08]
gehaeuse/vorschau_esp.png

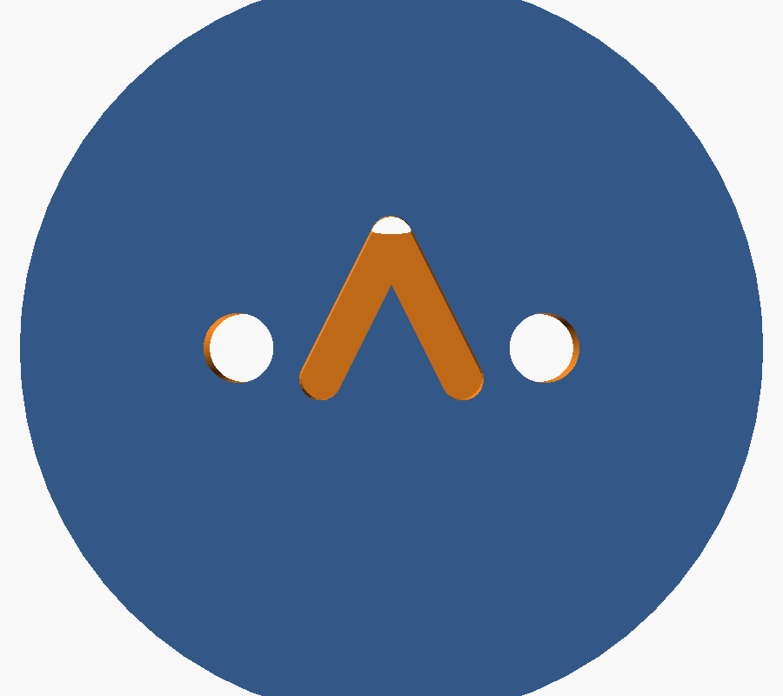
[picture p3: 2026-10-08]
gehaeuse/vorschau_kopf_vorn.png

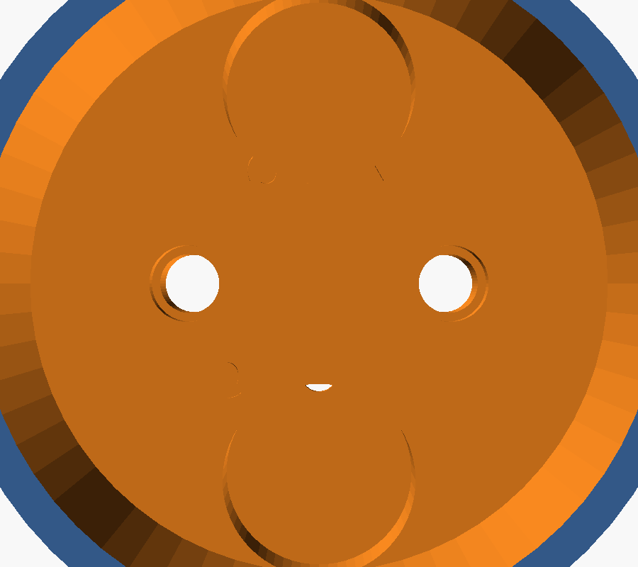
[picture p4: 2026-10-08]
gehaeuse/vorschau_kopf_hinten.png

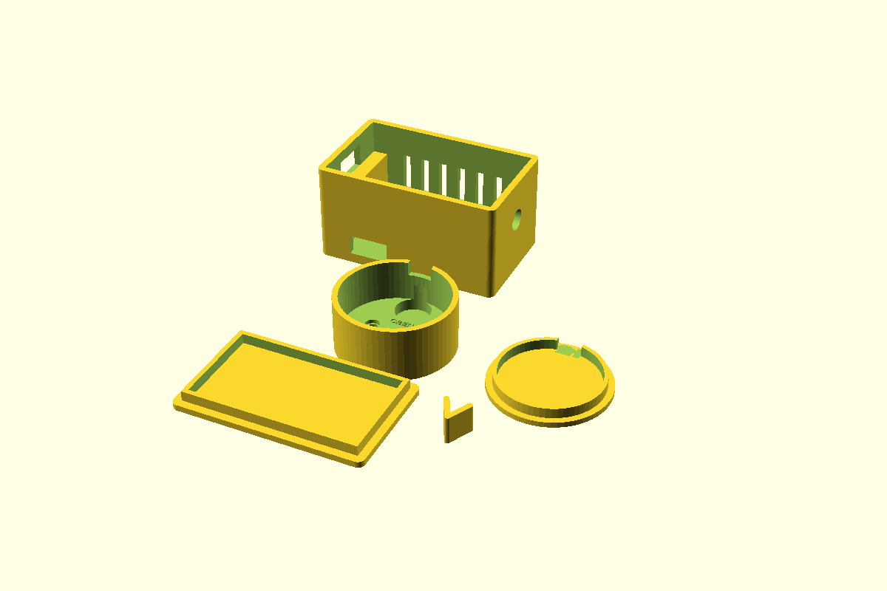
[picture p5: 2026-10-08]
gehaeuse/vorschau_alle.png

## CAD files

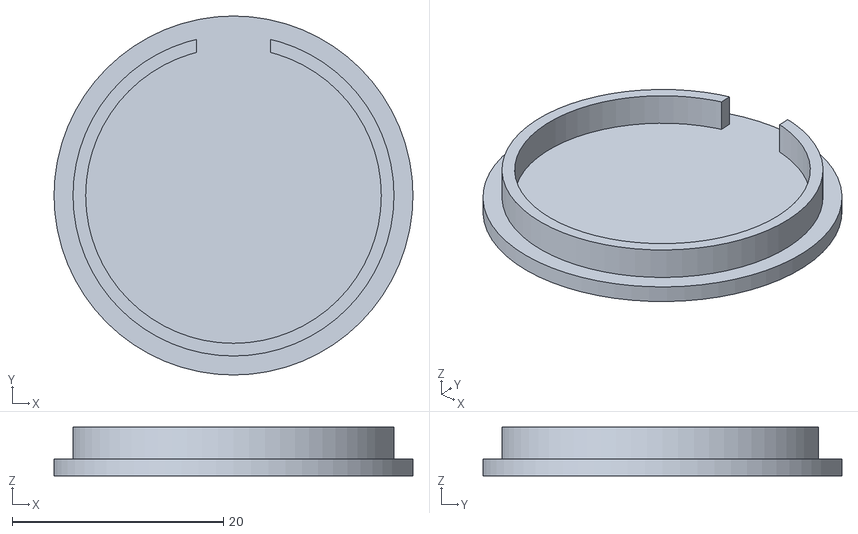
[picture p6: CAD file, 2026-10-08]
gehaeuse/kopf_deckel.stl
34.0 x 34.0 x 4.60

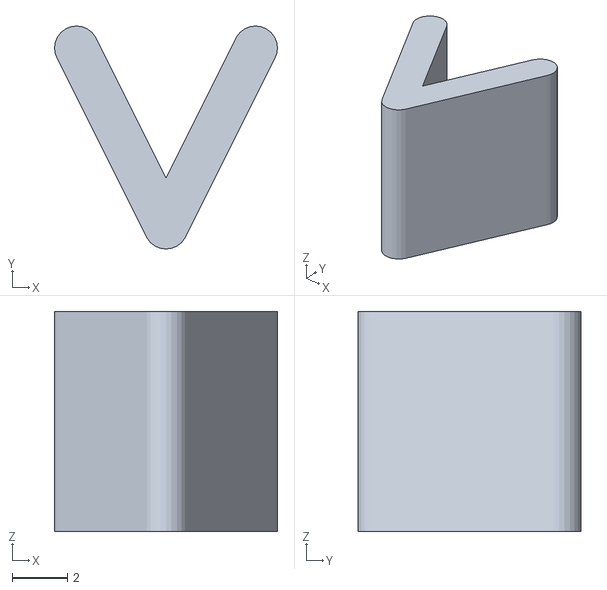
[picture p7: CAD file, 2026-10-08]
gehaeuse/v_schluessel.stl
8.10 x 8.10 x 8.00

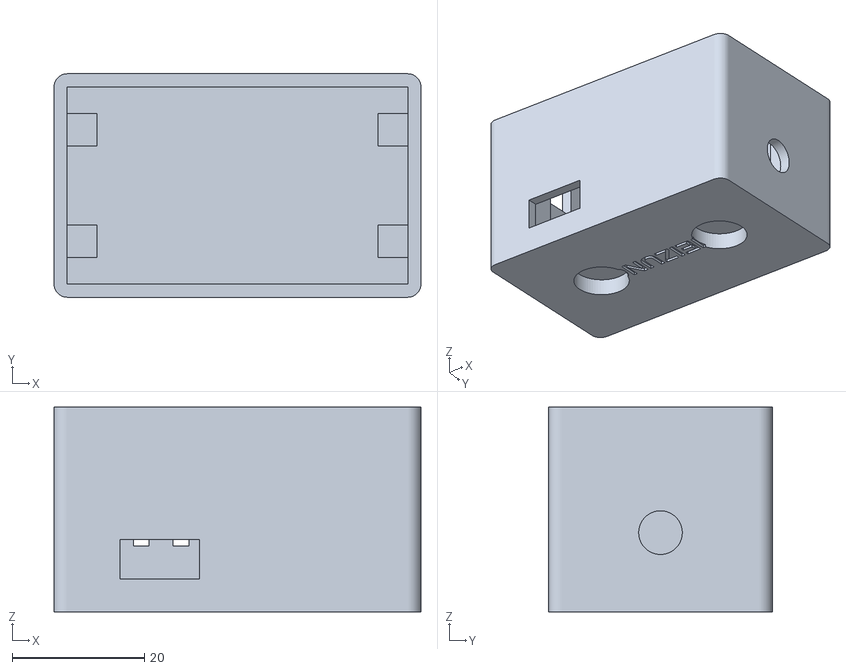
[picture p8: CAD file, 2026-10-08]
gehaeuse/esp.stl
55.5 x 33.8 x 31.0

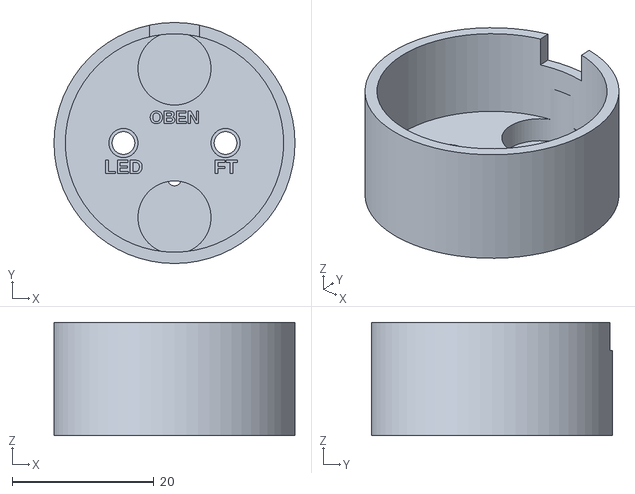
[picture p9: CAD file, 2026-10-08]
gehaeuse/kopf.stl
34.0 x 34.0 x 16.0

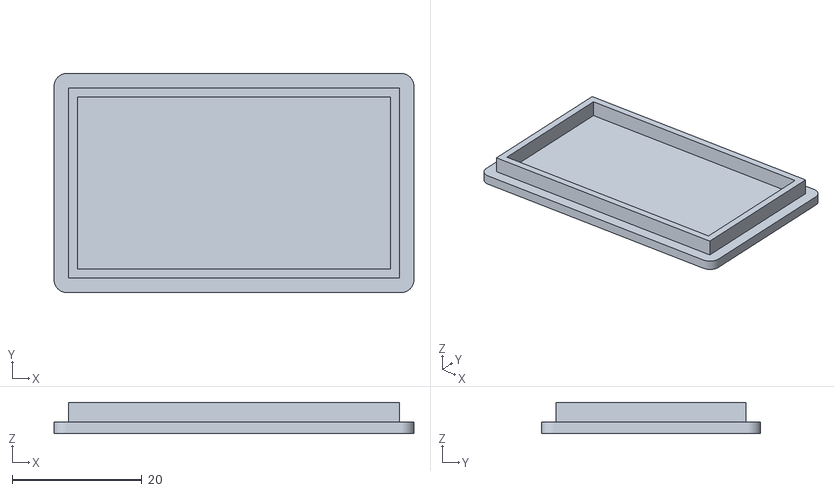
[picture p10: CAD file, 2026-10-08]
gehaeuse/esp_deckel.stl
55.5 x 33.8 x 4.80

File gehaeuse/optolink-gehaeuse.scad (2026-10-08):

// Optolink-Lesekopf + ESP32-Gehaeuse fuer Vitotronic 200 KW2 (Viessmann Vitola 111)
// Stand 04.10.2026 — Notiz project_oeltank_fuellstandsensor
//
// Teile (Auswahl ueber TEIL, oder alle nebeneinander mit TEIL="alle"):
//   "kopf"        Lesekopf (Front nach unten drucken)
//   "v_schluessel" Fuehrungs-V, wird in die Front gesteckt/geklebt und greift ins „Viessmann-V“
//   "kopf_deckel" Rueckdeckel des Lesekopfs mit Kabelauslass
//   "esp"         Gehaeuse fuer ESP32-DevKitC V4 (WROOM-32U), Magnete hinten fuer das Kesselblech
//   "esp_deckel"  Deckel dazu
//
// Optolink-Geometrie aus dem openv-Wiki (files/vito.scad): Optik-Fenster 14 mm auseinander
// (±7 mm), runde Auflageflaeche Ø34 mm, Fuehrungs-„V“ ragt hoechstens 8 mm in die Regelung.
// Vitotronic: LINKE Lampe (rot, Stoerung) = IR-Empfaenger → dort sitzt UNSERE IR-LED;
//             RECHTE Lampe (gruen, Betrieb) = IR-Sender → dort sitzt UNSER Fototransistor.
// „Links/rechts“ gilt mit Blick AUF die Regelung. Blickt man beim Aufsetzen auf die Rueckseite des
// Kopfs, stimmt die Seite ueberein: LED links, FT rechts (innen eingepraegt, „OBEN“ nach oben).
//
// VOR DEM DRUCK MESSEN (Messschieber) und unten anpassen:
//   - Abstand der beiden Lampen-Mitten an der Regelung   → fenster_abstand (Wiki: 14)
//   - ESP32-Platine Laenge x Breite                         → esp_l, esp_b (DevKitC V4 meist ~55 x 28)
// Material: PETG (Kesselnaehe), 0,2 mm Schicht, 3 Waende, ohne Stuetzen.
// Platine im ESP-Gehaeuse: liegt an beiden Stirnseiten auf je zwei Stuetzen ZWISCHEN den Stiftleisten
// (links/rechts der Mitte, Mitte frei fuer USB-Loetlaschen bzw. SMA-Mutter), bei Bedarf mit Heisskleber fixieren.

TEIL = "alle";

$fn = 64;

// ---------- Lesekopf ----------
kopf_d          = 34;     // Auflageflaeche
platte          = 4;      // Frontplatte; 3-mm-LED/FT liegen mit der Linse buendig
fenster_abstand = 14.4;   // Mitte-Mitte der Lampen, Jens gemessen 06.10. (Wiki: 14)
loch_d          = 3.2;    // 3 mm Bauteil + Spiel
kragen_d        = 4.1;    // Kragen am Bauteilfuss (3-mm-LEDs: ~3,8 mm)
kragen_t        = 1.2;    // Kragen-Anschlag von hinten
v_hoehe         = 6;      // wie weit der Fuehrungs-V-Steg vorsteht (max. 8)
v_breite        = 6.5;
v_dicke         = 1.6;    // Stegstaerke des V
v_versatz_y     = -1.5;   // V liegt minimal unter der Fensterlinie (wie vito.scad)
v_zapfen        = 2;      // Zapfen des V-Schluessels in der Front
wand            = 1.6;
kopf_tiefe      = 12;     // Hohlraum fuer Widerstaende + Loetstellen
magnet_d        = 10.3;   // Neodym 10 x 3 mm + Spiel
magnet_h        = 3.2;
magnet_haut     = 0.6;    // Restwand zur Front (Magnet haelt durch)
magnet_y        = 10.5;   // ober- und unterhalb der Fensterlinie
kabel_b         = 7;      // Auslass fuer 4 Litzen
kabel_h         = 4;

// ---------- ESP32-Gehaeuse ----------
esp_l   = 49.9;   // Platine 48,24 + USB-C-Ueberstand 1,6 (Jens gemessen 06.10.)
esp_b   = 28.2;   // Platine 28,15 (Jens gemessen 06.10.)
spiel   = 0.8;    // rundum
ew      = 2.0;    // Wandstaerke
boden   = 4.0;    // 07.10.: war 2,0 → Magnettaschen (3,2 tief) gingen DURCH den Boden; jetzt 0,8 mm Restwand
auflage_h = 17;   // Platinenunterkante ueber Boden: Stiftleisten + Dupont-Buchsen darunter
auflage_t = 4.5;  // wie weit die Auflagen unter die Platinen-Stirnseiten greifen
innen_h = 27;     // Innenhoehe bis Deckel
usb_b = 12; usb_h = 7;          // Ausschnitt fuer USB-C-Stecker (mit Tuelle)
usb_ueber_platte = 1.6;         // Mitte USB-C ueber Platinenoberseite (ca.)
sma_d = 6.6;                    // SMA-Buchse der Antennen-Kit-Pigtail (1/4"-Gewinde)
sma_z = 8;                      // Mitte SMA ueber Boden (unter der Platine)
sma_luecke = 12;                // freie Breite zwischen den Stuetzen: SMA-Mutter (SW 8, ueber Ecken ~9,2) bzw. Loetlaschen der USB-C-Buchse
stift_rand = 3.2;               // 07.10.: Stiftleisten laufen ueber die GANZE Platinenlaenge (19 x 2,54 = 48,3) —
                                // Reihen 1,4 mm vom Rand, Kunststoff + Dupont bis ~2,7 mm → Stuetzen bleiben 3,2 mm vom Laengsrand weg
dup_b = 12; dup_h = 6;          // Auslass fuer die 4 Dupont-Leitungen (seitlich unten)

iL = esp_l + 2*spiel;
iB = esp_b + 2*spiel;
aL = iL + 2*ew;
aB = iB + 2*ew;
aH = boden + innen_h;

// ===================================================================
module text_flach(t, s=3) {
    linear_extrude(0.6) text(t, size=s, font="Liberation Sans:style=Bold", halign="center", valign="center");
}

module v_steg(h, d) {
    // „V“ aus zwei Stegen, Spitze nach unten (-y)
    for (s=[-1,1])
        hull() {
            translate([0, -v_breite*0.55, 0]) cylinder(d=d, h=h, $fn=24);
            translate([s*v_breite/2, v_breite*0.45, 0]) cylinder(d=d, h=h, $fn=24);
        }
}

module kopf() {
    // Front liegt auf z=0 (zur Regelung) und wird so auch gedruckt: Front aufs Bett.
    difference() {
        union() {
            cylinder(d=kopf_d, h=platte + kopf_tiefe);
        }
        // Hohlraum von hinten
        translate([0,0,platte]) cylinder(d=kopf_d-2*wand, h=kopf_tiefe+1);
        // Optik-Fenster durchgehend + Kragenanschlag von hinten
        for (x=[-fenster_abstand/2, fenster_abstand/2]) {
            translate([x,0,-1]) cylinder(d=loch_d, h=platte+2);
            translate([x,0,platte-kragen_t]) cylinder(d=kragen_d, h=kragen_t+1);
        }
        // Magnettaschen von hinten, vorn bleibt magnet_haut stehen
        for (y=[-magnet_y, magnet_y])
            translate([0,y,magnet_haut]) cylinder(d=magnet_d, h=magnet_h+5);
        // Kabelauslass oben in der Wand
        translate([-kabel_b/2, kopf_d/2-wand-1, platte+kopf_tiefe-kabel_h]) cube([kabel_b, wand+2, kabel_h+1]);
        // Tasche fuer den Zapfen des V-Schluessels (von vorn)
        translate([0, v_versatz_y, -0.01]) v_steg(v_zapfen+0.2, v_dicke+0.35);
        // Kennzeichnung innen auf der Frontplatte, lesbar von hinten
        translate([-fenster_abstand/2, -3.4, platte-0.4]) text_flach("LED", 2.0);
        translate([ fenster_abstand/2, -3.4, platte-0.4]) text_flach("FT", 2.0);
        translate([0, 3.6, platte-0.4]) text_flach("OBEN", 1.8);
    }
}

module v_schluessel() {
    v_steg(v_hoehe + v_zapfen, v_dicke);
}

module kopf_deckel() {
    d_innen = kopf_d - 2*wand - 0.4;   // Steckpassung
    difference() {
        union() {
            cylinder(d=kopf_d, h=1.6);
            translate([0,0,1.6]) difference() {
                cylinder(d=d_innen, h=3);
                translate([0,0,-1]) cylinder(d=d_innen-2.4, h=5);
            }
        }
        // Gegenstueck zum Kabelauslass im Steckkragen
        translate([-kabel_b/2, d_innen/2-3, 1.6]) cube([kabel_b, 4, 4]);
    }
}

// ===================================================================
module esp() {
    platte_ok = boden + auflage_h;           // Platinenunterkante
    usb_z = platte_ok + 1.6 + usb_ueber_platte;
    difference() {
        // Aussenkoerper mit abgerundeten Kanten
        hull() for (x=[2, aL-2], y=[2, aB-2]) translate([x,y,0]) cylinder(r=2, h=aH);
        // Innenraum
        translate([ew, ew, boden]) cube([iL, iB, innen_h+1]);
        // USB-C an der linken Stirnseite (x=0)
        translate([-1, aB/2-usb_b/2, usb_z-usb_h/2]) cube([ew+2, usb_b, usb_h]);
        // SMA-Antennenbuchse an der rechten Stirnseite, UNTER der Platine (dort ist Platz fuer die Mutter;
        // oben wuerde sie mit dem Steckrand des Deckels kollidieren)
        translate([aL-ew-1, aB/2, boden+sma_z]) rotate([0,90,0]) cylinder(d=sma_d, h=ew+2);
        // Dupont-Auslass seitlich unten (Langseite y=0), nahe der USB-Seite
        translate([ew+8, -1, boden+1]) cube([dup_b, ew+2, dup_h]);
        // Lueftungsschlitze in der Gegenseite
        for (i=[0:5]) translate([ew+10+i*6, aB-ew-1, boden+6]) cube([2.4, ew+2, 12]);
        // Magnettaschen im Boden (von unten), fuer das Stahlblech des Kessels
        for (x=[aL*0.25, aL*0.75]) translate([x, aB/2, -0.01]) cylinder(d=magnet_d, h=magnet_h);
        // Kennzeichnung
        translate([aL/2, aB/2, -0.01]) mirror([1,0,0]) linear_extrude(0.5)
            text("HEIZUNG", size=4, font="Liberation Sans:style=Bold", halign="center", valign="center");
    }
    // Stuetzen fuer die Platinen-Stirnseiten: je Stirnseite zwei, zwischen Stiftleiste und Mitte.
    // 07.10.: vorher durchgehende Auflage → die nach unten zeigenden Stifte sassen darauf auf.
    st_b = esp_b/2 - stift_rand - sma_luecke/2;      // Breite je Stuetze (~4,9 mm)
    for (x=[ew, ew+iL-auflage_t], s=[-1,1])
        translate([x, aB/2 + (s>0 ? sma_luecke/2 : -sma_luecke/2 - st_b), boden])
            cube([auflage_t, st_b, auflage_h]);
}
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

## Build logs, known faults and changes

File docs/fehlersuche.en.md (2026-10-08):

🇩🇪 [Deutsche Version](fehlersuche.md)

# Troubleshooting

## Failure patterns that have already occurred

| Symptom | Cause | Solution | Date |
|---|---|---|---|
| Fallback hotspot does not accept the password | The **test build with dummy secrets** was flashed (wrong hotspot password, wrong API key) | Never flash a test build; reflash with real secrets and verify via the API | 06.10. |
| Second flash attempt uploads the old firmware again | `esphome upload` does **not** recompile, it takes the last build from `.esphome/` | For real firmware always use `esphome run …`; watch for "Successfully compiled" | 06.10. |
| USB port locked after replugging (Linux) | `/dev/ttyUSB0` is recreated every time it is plugged in, a `setfacl` permission is lost | Since 07.10. udev rule on the PC (`70-esp-seriell.rules`, CP210x/CH340/Espressif, `uaccess`) – no more `setfacl` needed | 06./07.10. |
| SMA hole not usable in the print | Hole was behind the right-hand board support | Hole moved below the board (`sma_z = 8`), 12 mm gap | 06.10. |
| Magnet pockets go through the floor | Pocket depth 3.2 mm > floor thickness 2.0 mm | `boden = 4.0` | 07.10. |
| Board does not sit flat, pins hit the supports | Pin headers run along the entire board length; continuous supports | 4 individual supports between the pin rows (3.2 mm from the edge, 12 mm free in the middle) | 07.10. |

Another flashing error ("No more data to read" at 460800 baud) occurred on the **tank-level ESP32**, not on this
device. If it occurs here: write the finished `firmware.factory.bin` with `esptool … --baud 115200`.

## Expected failure patterns during commissioning (not yet occurred)

| Symptom | Possible cause | Check / solution |
|---|---|---|
| All Optolink values `unknown`, "Optolink-Status" stays `communication state unknown` | Head not attached / rotated; LED and PT swapped; legs wrong | Check position: LED left (red lamp), PT right (green lamp), "OBEN" (top) at the top; polarity via diode test |
| No responses in the log, but the LED transmits | Phototransistor wrong polarity or 10 kΩ missing | Collector (short leg) to GPIO16 + 10 kΩ to 3V3, emitter to GND |
| LED does not transmit | LED reversed (cathode must go to GPIO17), 220 Ω open | Point a phone camera (without IR filter) at the LED – IR flicker visible during requests (general trick, not tried here) |
| Sporadic dropouts | Head not sitting flat, ambient light | Press the head on, check the V key; if necessary replace components with SFH487 / SFH309FA |
| Values plausible, but one quantity wrong | openv address does not match this system | Check the address using [`einmessen.en.md`](einmessen.en.md), correct or disable the entity |
| Outdoor temperature in winter 6000 °C or similar | Value read without sign | `min_value: -60` must be in the YAML (is set) |
| Device `unavailable` in HA | Wi-Fi, power | "WLAN-Signal" (Wi-Fi signal; measured at the boiler on 04.10. −41/−42 dBm), check the USB power supply; fallback hotspot `Heizung-Fallback` |

## Important for automations

Without a connection, the Optolink binary sensors report **`unknown`**, not `off`. "Brennerstörung (burner fault) = off" is therefore
no proof of fault-free operation – a permanent `unknown` must itself be treated as a problem.

## Distinction: heating reports D1

D1 = **burner fault**. On 03./04.10. the cause was an empty tank. After refilling on 05.10. the burner only ran
again after bleeding (filter, port P on the Danfoss pump BFP 21 L3) and a reset on the burner control unit LOA24
(red button). The "Entsperrung" (unlock) button on the controller is the **STB** (safety temperature limiter), not the burner reset.

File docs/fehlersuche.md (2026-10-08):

🇬🇧 [English version](fehlersuche.en.md)

# Fehlersuche

## Bereits aufgetretene Fehlerbilder

| Fehlerbild | Ursache | Lösung | Datum |
|---|---|---|---|
| Fallback-Hotspot nimmt das Passwort nicht an | Es wurde der **Prüfbuild mit Dummy-Secrets** geflasht (falsches Hotspot-Passwort, falscher API-Schlüssel) | Nie einen Prüfbuild flashen; mit echten Secrets neu flashen und per API gegenprüfen | 06.10. |
| Zweiter Flashversuch spielt wieder die alte Firmware auf | `esphome upload` kompiliert **nicht** neu, nimmt den letzten Build aus `.esphome/` | Für echte Firmware immer `esphome run …`; auf „Successfully compiled“ achten | 06.10. |
| USB-Port nach Umstecken gesperrt (Linux) | `/dev/ttyUSB0` wird bei jedem Anstecken neu angelegt, eine `setfacl`-Freigabe ist weg | Seit 07.10. udev-Regel am PC (`70-esp-seriell.rules`, CP210x/CH340/Espressif, `uaccess`) – kein `setfacl` mehr nötig | 06./07.10. |
| SMA-Bohrung im Druck nicht nutzbar | Bohrung lag hinter der rechten Platinenauflage | Bohrung unter die Platine verlegt (`sma_z = 8`), 12 mm Lücke | 06.10. |
| Magnettaschen gehen durch den Boden | Taschentiefe 3,2 mm > Bodenstärke 2,0 mm | `boden = 4.0` | 07.10. |
| Platine liegt nicht auf, Pins stoßen auf | Stiftleisten laufen über die ganze Platinenlänge; durchgehende Auflagen | 4 Einzelstützen zwischen den Pinreihen (3,2 mm vom Rand, 12 mm Mitte frei) | 07.10. |

Ein weiterer Flashfehler („No more data to read“ bei 460800 Baud) trat am **Tankmessungs-ESP32** auf, nicht an diesem
Gerät. Falls er hier auftritt: mit `esptool … --baud 115200` die fertige `firmware.factory.bin` schreiben.

## Erwartbare Fehlerbilder bei der Inbetriebnahme (noch nicht aufgetreten)

| Symptom | Mögliche Ursache | Prüfen / Lösung |
|---|---|---|
| Alle Optolink-Werte `unknown`, „Optolink-Status“ bleibt `communication state unknown` | Kopf nicht aufgesetzt / verdreht; LED und FT vertauscht; Beinchen falsch | Lage prüfen: LED links (rote Lampe), FT rechts (grüne Lampe), „OBEN“ oben; Polung per Diodentest |
| Keine Antworten im Log, LED sendet aber | Fototransistor falsch gepolt oder 10 kΩ fehlt | Kollektor (kurzes Bein) an GPIO16 + 10 kΩ nach 3V3, Emitter an GND |
| LED sendet nicht | LED verpolt (Kathode muss an GPIO17), 220 Ω offen | Handykamera (ohne IR-Filter) auf die LED richten – IR-Flackern bei Anfragen sichtbar (allgemeiner Kniff, hier nicht erprobt) |
| Sporadische Aussetzer | Kopf sitzt nicht plan, Fremdlicht | Kopf andrücken, V-Schlüssel prüfen; notfalls Bauteile gegen SFH487 / SFH309FA tauschen |
| Werte plausibel, aber eine Größe falsch | openv-Adresse passt nicht zu dieser Anlage | Adresse anhand [`einmessen.md`](einmessen.md) prüfen, Entität korrigieren oder deaktivieren |
| Außentemperatur im Winter 6000 °C o. ä. | Wert ohne Vorzeichen gelesen | `min_value: -60` muss in der YAML stehen (ist gesetzt) |
| Gerät in HA `unavailable` | WLAN, Strom | „WLAN-Signal“ (am Kessel am 04.10. −41/−42 dBm gemessen), USB-Netzteil prüfen; Fallback-Hotspot `Heizung-Fallback` |

## Wichtig für Automationen

Ohne Verbindung melden die Optolink-Binärsensoren **`unknown`**, nicht `off`. „Brennerstörung = aus“ ist deshalb
kein Beleg für störungsfreien Betrieb – ein dauerhaft `unknown` muss selbst als Problem gelten.

## Abgrenzung: Heizung meldet D1

D1 = **Brennerstörung**. Am 03./04.10. war die Ursache ein leerer Tank. Nach dem Befüllen am 05.10. lief der Brenner
erst nach Entlüften (Filter, Anschluss P an der Danfoss-Pumpe BFP 21 L3) und Reset am Feuerungsautomaten LOA24
(roter Knopf) wieder. Der Knopf „Entsperrung“ an der Regelung ist der **STB**, nicht der Brenner-Reset.

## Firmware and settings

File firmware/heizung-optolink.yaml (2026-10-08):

# Viessmann Vitola 111 / Vitotronic 200 Typ KW2 (Geraetekennung 0x2098) per Optolink
# Hardware: ESP32-WROOM-32U DevKitC V4 (externe Antenne) + DIY-Lesekopf am „V“ der Regelung
#   3,3 V ── 220 Ω ── IR-LED (Anode) │ Kathode ── GPIO17 (TX)    [Chanzon 940 nm, 3 mm]
#   3,3 V ── 10 kΩ ──┬── GPIO16 (RX)                              [Kingbright L-93DP3C]
#                    └── Kollektor Fototransistor │ Emitter ── GND
#   Schaltung nach VitoWiFi/openv-Wiki („Die Optolink-Schnittstelle“, „ESPHome-Optolink“).
# Komponente: ESPHome-PR #4453 (j0ta29, Stand 17.09.2026), Protokoll KW (VS1), 4800 8E2.
# Adressen: openv-Wiki „Adressen“, Spalte V200KW2/KW1.
# Bewusst NUR LESEND — keine number/select/switch, die in die Regelung schreiben.
# Stand 04.10.2026, Notiz project_oeltank_fuellstandsensor.

substitutions:
  name: heizung-optolink
  friendly_name: Heizung

esphome:
  name: ${name}
  friendly_name: ${friendly_name}
  comment: Vitotronic 200 KW2 per Optolink (nur lesend)

esp32:
  board: esp32dev
  framework:
    type: arduino   # Optolink-Komponente laeuft nur mit Arduino

external_components:
  - source: github://pr#4453
    components: [optolink]

logger:
  level: INFO       # UART0 bleibt frei fuer USB-Log, Optolink laeuft auf eigenen Pins

api:
  encryption:
    key: !secret heizung_api_key

ota:
  - platform: esphome   # Updates per WLAN, abgesichert ueber den API-Schluessel

wifi:
  ssid: !secret wifi_ssid
  password: !secret wifi_password
  ap:
    ssid: Heizung-Fallback
    password: !secret heizung_ap_password

captive_portal:

optolink:
  protocol: KW
  rx_pin: GPIO16
  tx_pin: GPIO17
  logger: false     # fuer die Inbetriebnahme auf true stellen

text_sensor:
  - platform: optolink
    type: DEVICE_INFO
    name: Gerätekennung
    entity_category: diagnostic
    update_interval: 1800s
  - platform: optolink
    type: STATE_INFO
    name: Optolink-Status
    entity_category: diagnostic
    update_interval: 30s

binary_sensor:
  - platform: optolink
    name: Brennerstörung            # = Anzeige D1
    address: 0x0883
    device_class: problem
    update_interval: 15s
  - platform: optolink
    name: Sammelstörung
    address: 0x0847
    device_class: problem
    update_interval: 15s
  - platform: optolink
    name: Brenner
    address: 0x0842                 # Zustand 1. Stufe
    device_class: running
    update_interval: 15s
  - platform: optolink
    name: Speicherladepumpe
    address: 0x0845
    device_class: running
    update_interval: 60s
  - platform: optolink
    name: Zirkulationspumpe
    address: 0x0846
    device_class: running
    update_interval: 60s
  - platform: optolink
    name: Heizkreispumpe
    address: 0x2906
    device_class: running
    update_interval: 60s

sensor:
  # --- Temperaturen ---
  - platform: optolink
    name: Außentemperatur
    address: 0x0800
    bytes: 2
    div_ratio: 10
    min_value: -60                  # negativ → Wert wird vorzeichenbehaftet gelesen
    unit_of_measurement: °C
    device_class: temperature
    state_class: measurement
    accuracy_decimals: 1
    update_interval: 120s
  - platform: optolink
    name: Außentemperatur gedämpft
    address: 0x5527
    bytes: 2
    div_ratio: 10
    min_value: -60
    unit_of_measurement: °C
    device_class: temperature
    state_class: measurement
    accuracy_decimals: 1
    update_interval: 600s
  - platform: optolink
    name: Kesseltemperatur
    address: 0x0802
    bytes: 2
    div_ratio: 10
    unit_of_measurement: °C
    device_class: temperature
    state_class: measurement
    accuracy_decimals: 1
    update_interval: 60s
  - platform: optolink
    name: Kesselsolltemperatur
    address: 0x555A
    bytes: 2
    div_ratio: 10
    unit_of_measurement: °C
    device_class: temperature
    state_class: measurement
    accuracy_decimals: 1
    update_interval: 120s
  - platform: optolink
    name: Warmwassertemperatur
    address: 0x0804                 # Speicher (Sensor 5)
    bytes: 2
    div_ratio: 10
    unit_of_measurement: °C
    device_class: temperature
    state_class: measurement
    accuracy_decimals: 1
    update_interval: 120s
  - platform: optolink
    name: Vorlauftemperatur
    address: 0x080C                 # Sensor 17B
    bytes: 2
    div_ratio: 10
    unit_of_measurement: °C
    device_class: temperature
    state_class: measurement
    accuracy_decimals: 1
    update_interval: 120s
  - platform: optolink
    name: Vorlaufsolltemperatur
    address: 0x2544                 # A1M1
    bytes: 2
    div_ratio: 10
    unit_of_measurement: °C
    device_class: temperature
    state_class: measurement
    accuracy_decimals: 1
    update_interval: 300s
  - platform: optolink
    name: Abgastemperatur           # nur sinnvoll, wenn ein Abgasfuehler verbaut ist
    address: 0x0808
    bytes: 2
    div_ratio: 10
    unit_of_measurement: °C
    device_class: temperature
    state_class: measurement
    accuracy_decimals: 1
    entity_category: diagnostic
    update_interval: 300s
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

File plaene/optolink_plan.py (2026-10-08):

import matplotlib; matplotlib.use("Agg")
import matplotlib.pyplot as plt
from matplotlib.patches import Rectangle, Polygon, Circle, FancyArrowPatch
fig = plt.figure(figsize=(8.27, 11.69)); ax = fig.add_axes([0,0,1,1]); ax.set_xlim(0,210); ax.set_ylim(0,297); ax.axis("off")
L = dict(color="black", lw=1.4)
def line(*pts, **kw): ax.plot([p[0] for p in pts],[p[1] for p in pts], **{**L, **kw})
def dot(x,y): ax.add_patch(Circle((x,y),0.9,color="black"))
def res(x,y1,y2,label):  # senkrechter Widerstand
    m=(y1+y2)/2; line((x,y1),(x,m+6)); line((x,m-6),(x,y2)); ax.add_patch(Rectangle((x-2.5,m-6),5,12,fill=False,lw=1.4))
    ax.text(x+4.5,m,label,va="center",fontsize=11,fontweight="bold")
def pfeile(x,y,richtung):
    for d in (0,4):
        if richtung=="raus": ax.add_patch(FancyArrowPatch((x+3,y+d),(x+10,y+d+5),arrowstyle="-|>",mutation_scale=9,color="crimson",lw=1.1))
        else: ax.add_patch(FancyArrowPatch((x-10,y+d+5),(x-3,y+d),arrowstyle="-|>",mutation_scale=9,color="crimson",lw=1.1))
T=lambda x,y,s,**k: ax.text(x,y,s,**{"fontsize":10,**k})
T(15,282,"Optolink-Lesekopf – Schaltplan",fontsize=18,fontweight="bold")
T(15,274,"Vitotronic 200 KW2 · ESP32-WROOM-32U DevKitC · ESPHome heizung-optolink (192.168.178.193) · Stand 06.10.2026",fontsize=8.5)

# Schienen
y3, yg = 240, 150
T(12,y3+2,"3V3",fontsize=12,fontweight="bold",color="firebrick"); line((25,y3),(170,y3),color="firebrick",lw=2)
T(12,yg-1,"GND",fontsize=12,fontweight="bold"); line((25,yg),(170,yg),lw=2)

# --- Sender: 3V3 - 220 - LED - GPIO17
xs=60; dot(xs,y3); res(xs,y3,212,"220 Ω")
# LED (Anode oben, Kathode unten), Dreieck nach unten
line((xs,212),(xs,203)); ax.add_patch(Polygon([(xs-5,203),(xs+5,203),(xs,195)],closed=True,fill=False,lw=1.4)); line((xs-5,195),(xs+5,195)); line((xs,195),(xs,180))
pfeile(xs+4,197,"raus")
T(xs-36,201,"IR-LED 940 nm\n(Chanzon 3 mm)",fontsize=8.5)
T(xs+8,207,"Anode (langes Bein)",fontsize=8); T(xs+8,190,"Kathode (kurz, flache Seite)",fontsize=8)
line((xs,180),(xs,170)); ax.add_patch(Rectangle((xs-14,162),28,8,fill=False,lw=1.4)); T(xs-12,164.5,"GPIO17 (TX)",fontsize=9,fontweight="bold")
T(xs-30,154,"SENDEN → zur LINKEN Lampe",fontsize=8.5,color="crimson")

# --- Empfaenger: 3V3 - 10k - Knoten - GPIO16 ; Knoten - Kollektor FT - Emitter - GND
xr=140; dot(xr,y3); res(xr,y3,212,"10 kΩ")
line((xr,212),(xr,200)); dot(xr,200); line((xr,200),(xr-25,200),(xr-25,176))
ax.add_patch(Rectangle((xr-39,168),28,8,fill=False,lw=1.4)); T(xr-37,170.5,"GPIO16 (RX)",fontsize=9,fontweight="bold")
# Fototransistor (Kreis, Basis-Pfeile)
cx,cy=xr,183; ax.add_patch(Circle((cx,cy),7,fill=False,lw=1.4))
line((xr,200),(xr,190)); line((cx-2,190),(cx-2,176)) # Basisbalken
line((xr,190),(cx-2,186)); line((cx-2,180),(xr,176)); line((xr,176),(xr,yg)); dot(xr,yg)
ax.add_patch(FancyArrowPatch((cx-2,180),(xr+0.3,176.3),arrowstyle="-|>",mutation_scale=8,color="black",lw=1))
pfeile(cx-7,186,"rein")
T(xr+9,190,"Kollektor (meist kurzes\nBein – prüfen!)",fontsize=8); T(xr+9,173,"Emitter (meist langes Bein)",fontsize=8)
T(xr+9,182,"Fototransistor\nKingbright L-93DP3C",fontsize=8.5)
T(xr-30,154,"EMPFANGEN ← von der RECHTEN Lampe",fontsize=8.5,color="crimson")

# Hinweis Beinchen
T(15,135,"Achtung Beinchen: Bei der LED ist das LANGE Bein die Anode (+). Beim Fototransistor ist meist das LANGE Bein der Emitter (−)\n"
        "→ vor dem Löten am Datenblatt bzw. mit dem Multimeter (Diodentest) prüfen. Falsch herum: nichts kaputt, aber keine Daten.",fontsize=8.3)

# Tabelle Anschluesse
T(15,118,"Verbindung Lesekopf ↔ ESP32 (4 Dupont-Leitungen, Buchse–Buchse)",fontsize=11,fontweight="bold")
rows=[("Leitung","ESP32-Pin","Im Lesekopf an","Farbvorschlag"),
      ("1","3V3","220 Ω (LED) + 10 kΩ (FT)","rot"),
      ("2","GND","Emitter Fototransistor","schwarz"),
      ("3","GPIO17 / „TX2“ / „17“","Kathode IR-LED","gelb"),
      ("4","GPIO16 / „RX2“ / „16“","Kollektor FT + 10 kΩ","grün")]
x0=[15,35,85,155]; yy=110
for i,r in enumerate(rows):
    for j,c in enumerate(r): T(x0[j],yy-i*7,c,fontsize=9,fontweight="bold" if i==0 else "normal")
    line((15,yy-i*7-2.5),(195,yy-i*7-2.5),lw=0.6)

# Kopf-Ansicht
T(15,68,"Lage im Lesekopf (Blick AUF die Regelung = Blick auf die Rückseite des Kopfs)",fontsize=11,fontweight="bold")
ax.add_patch(Circle((60,40),17,fill=False,lw=1.4)); ax.add_patch(Circle((52.8,40),1.6,color="crimson")); ax.add_patch(Circle((67.2,40),1.6,color="seagreen"))
T(44,33,"LED",fontsize=9); T(64,33,"FT",fontsize=9); T(55,55,"OBEN",fontsize=8); line((52.8,44),(67.2,44),lw=0.6); T(53.5,45.2,"14,4 mm",fontsize=7.5)
T(85,49,"• LINKE Lampe (rot, Störung) = Empfänger der Regelung\n   → dort unsere IR-LED",fontsize=8.8)
T(85,39,"• RECHTE Lampe (grün, Betrieb) = Sender der Regelung\n   → dort unser Fototransistor",fontsize=8.8)
T(85,31,"• Abstand Mitte–Mitte 14,4 mm (gemessen 06.10.), Kopf-STL ist angepasst",fontsize=8.8)
T(85,25,"• Widerstände sitzen im Kopf, nur 4 Leitungen zum ESP-Gehäuse",fontsize=8.8)
T(15,4,"Quelle: Schaltung nach VitoWiFi/openv-Wiki („Die Optolink-Schnittstelle“, „ESPHome-Optolink“), festgelegt 04.10.\nin ~/esphome/heizung-optolink.yaml. "
        "UART 4800 8E2, Protokoll KW. Inbetriebnahme: optolink → logger: true,\nWerte mit der Anzeige der Regelung vergleichen.",fontsize=7.5,color="dimgray")
fig.savefig("optolink-schaltplan.pdf")

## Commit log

2026-10-08 Initial commit: firmware, plans, enclosures and documentation (DE/EN)
    [esp.stl, esp_deckel.stl, kopf.stl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]
2026-10-09 Status: Fototransistor noch nicht da, Lesekopf-Termin auf 10.10. verschoben
    Kingbright L-93DP3C nicht geliefert; SFH 309 FA (Reichelt) als Vorsorge bestellt.
    README DE/EN und Verlauf nachgezogen.
    Fixes #1
2026-10-13 Stand 13.10.: Optolink in Betrieb, Adressen geprüft, DS18B20 Zirkulation
    - Firmware: geprüfte Adressen (Kessel-Soll 0x5502, Heizkreis M2, WW-Soll,
    Heizkurve), Busentlastung, Neustart-Grund, Sammelstörung delayed_on 30min,
    DS18B20 „Zirkulation Rücklauf“ an GPIO4
    - Gehäuse: Lesekopf 2,4 mm tiefer (v_versatz_y 0,9), kopf.stl neu
    - Pläne: Schaltplan auf SFH 309, ESP32-Belegung, DS18B20-Anschlussplan
    - Doku DE/EN: Status, Entitäten, HA-Anbindung, Verlauf 10.–13.10.,
    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
2026-10-14 Firmware: accept only 0/1 for switch states (sync byte 0x05 after bus suspension)
    Fixes #9
2026-10-19 Firmware: discard heating curve slope 0.5 (sync byte 0x05)
    The slope 0x2305 alternated between 1.4 and 0.5 since 15.10.; 0.5 is the
    raw sync byte 0x05 divided by 10. Level 0x2304 stays unfiltered (never
    showed 5, and 5 K is a plausible real value).
    Fixes #11
2026-10-22 Firmware + HA: write room setpoint HC2 (0x3306) with read-back
    First writing data point: number "Raumsoll HK2 einstellen" (18-28 °C) plus
    read sensor "Raumsoll HK2". Verified at the controller display (26, back to 25).
    A write can be lost silently during a bus suspension, so the HA script
    reads back and retries up to 3 times.
    Fixes #13
2026-10-22 Firmware: read heating curve and operating mode from circuit M2
    0x2305/0x2304/0x2301 belong to heating circuit 1, which is unused here.
    Switched to 0x3305/0x3304/0x3301 (M2). Curve identical (1.4 / 0),
    operating mode M2 = 3 instead of 0.
    Fixes #15
